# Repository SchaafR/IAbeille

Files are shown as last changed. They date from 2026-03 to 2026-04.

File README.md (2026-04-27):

# IABEILLES — Système de surveillance de ruches intelligent





**IABEILLES** est une solution IoT (Internet des Objets) développée à Polytech Sorbonne pour protéger les colonies d'abeilles contre la prédation des frelons asiatiques. Le système utilise l'intelligence artificielle pour la détection visuelle et sonore, tout en transmettant des données environnementales via le réseau LoRaWAN.

---

## Table des Matières
* [Présentation](#-présentation)
* [Spécifications Matérielles](#-spécifications-matérielles)
* [Installation Logicielle](#-installation-logicielle)
* [Configuration Réseau (LoRaWAN/TTN)](#-configuration-réseau)
* [Mise en Service](#-mise-en-service)
* [Équipe](#-équipe)

---

## Présentation

### Mission
Transformer des mesures physiques en **informations exploitables** pour les apiculteurs et chercheurs. Le système surveille en temps réel :
* **Détection visuelle** (IA) : Identification des abeilles et frelons.
* **Détection sonore** : Analyse de l'activité acoustique.
* **Environnement** : Température, humidité et luminosité.

### Architecture de communication
`Capteurs (I2C/Analog)` ➔ `ESP32S3 / Nano BLE` ➔ `Module LoRa E5` ➔ `Passerelle LoRaWAN` ➔ `TTN` ➔ `Bleep (Dashboard)`

---

## Spécifications Matérielles

| Composant | Rôle Principal |
| :--- | :--- |
| **XIAO ESP32S3 Sense** | Cœur de l'IA (Vision) & Caméra |
| **Arduino Nano BLE Sense** | Analyse sonore & Gestion des capteurs |
| **Module LoRa E5** | Communication longue portée |
| **DHT22 & BH1750** | Monitoring Température/Humidité/Lumière |
| **Panneau Solaire & LiPo** | Autonomie énergétique (3.7V 1000mAh) |
| **PCB Custom** | Interconnexion et robustesse |

---

## Installation Logicielle

### 1. Prérequis
* [Arduino IDE](https://www.arduino.cc/en/software)
* Support de carte **ESP32 by Espressif Systems** (via le gestionnaire de cartes).
* Support de carte **Arduino Mbed OS Nano Boards**.

### 2. Récupération du projet
```bash
git clone https://github.com/SchaafR/IAbeille.git
```

### 3. Installation des Librairies Custom (IA)
Les modèles d'inférence sont fournis sous forme d'archives `.zip` dans le dossier `/data`.
1. Localisez votre dossier Arduino (ex: `Documents/Arduino/libraries`).
2. Décompressez-y les fichiers suivants :
   - `BeeGuardAI_Hornet_Bee_Bees_G1V2_inferencing.zip`
   - `Hornets_lib_3.zip`
3. Redémarrez l'IDE Arduino.

### 4. Dépendances Standard
Installez via le **Library Manager** d'Arduino :
* `DHT sensor library`
* `BH1750`

---

## Configuration Réseau

### The Things Network (TTN)
Le module LoRa E5 utilise l'activation **OTAA**.
1. **Créer une application** sur [TTN Console](https://console.cloud.thethings.network/).
2. **Enregistrer l'appareil** avec les identifiants présents dans le code source :
   - `DevEUI`
   - `AppEUI` / `JoinEUI`
   - `AppKey`
3. **Payload Formatter** : Utilisez le script JavaScript situé dans `/src/payload_formatter` pour décoder les trames hexadécimales en données lisibles.

---

## Mise en Service

### Flashage des cartes
1. Ouvrez `COM_N_AI.ino` dans Arduino IDE.
2. Connectez le **XIAO ESP32S3**.
3. Sélectionnez le port correspondant et le type de carte **XIAO_ESP32S3**.
4. Cliquez sur **Upload** (→).
5. Répétez l'opération pour l'Arduino Nano avec le fichier `hornet_lib_3.ino`.

### Déploiement physique
> [!IMPORTANT]
> Vérifiez l'étanchéité du boîtier et le serrage des presse-étoupes avant l'installation en extérieur.

1. Actionnez le bouton **On/Off**.
2. Un **bip sonore (0.5s)** confirme l'initialisation du système.
3. Vérifiez la LED de charge (Panneau Solaire/Batterie).
4. Surveillez l'onglet **Live Data** sur TTN pour confirmer la réception des premières trames.

---

## Équipe (Rédacteurs)

* **Léo Dupuy**
* **Amine Filahi**
* **Benoit Lavieville**
* **Marguerite Massinga**
* **Rémy Schaaf**

---

## Remerciements
Projet réalisé dans le cadre de la 4ème année à **Polytech Sorbonne**. Merci à l'équipe pédagogique et aux encadrants pour leur soutien technique et méthodologique.

## Contacte
En cas de problème ou de questions, vous pouvez nous contacter à l'adresse : schaarem@gmail.com

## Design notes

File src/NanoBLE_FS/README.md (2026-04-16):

# Installation des dépendences

- Vérifie que HornetAudio.h est présente dans le dossier.
- Importer hornet_lib_3.zip dans l'IDE arduino (Sketch/Include Library/Include ZIP lib..)

# Variables globales de test 

- Mettre DEBUG @1
- Mettre Modefonctionnement @2

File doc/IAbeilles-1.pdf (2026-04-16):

# IAbeilles

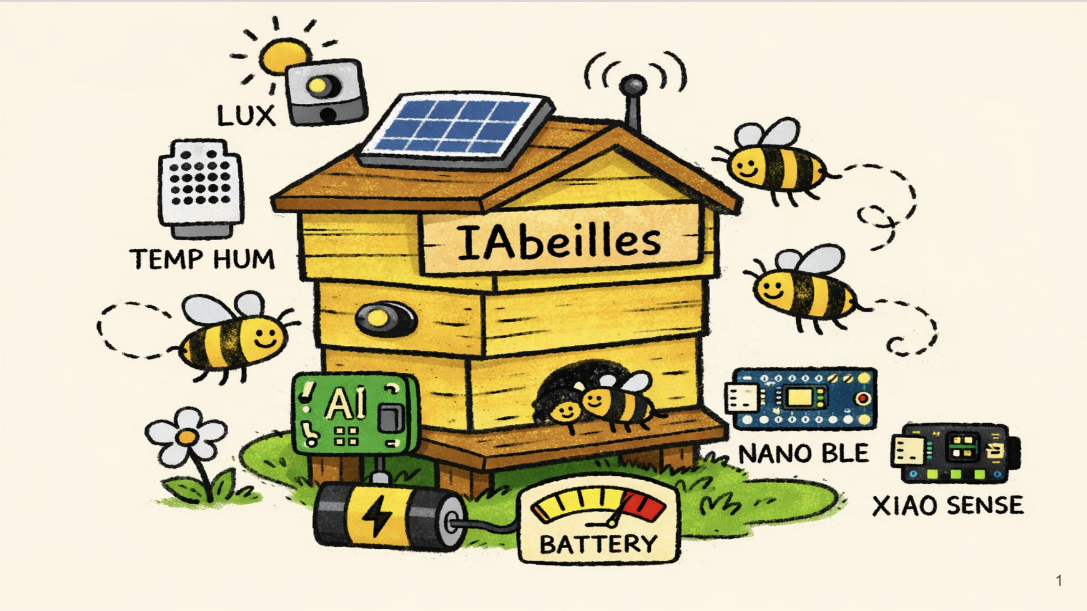
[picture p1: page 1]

- Léo Dupuy
- Amine Filahi
- Benoit Lavieville
- Marguerite Massinga
- Rémy Schaaf

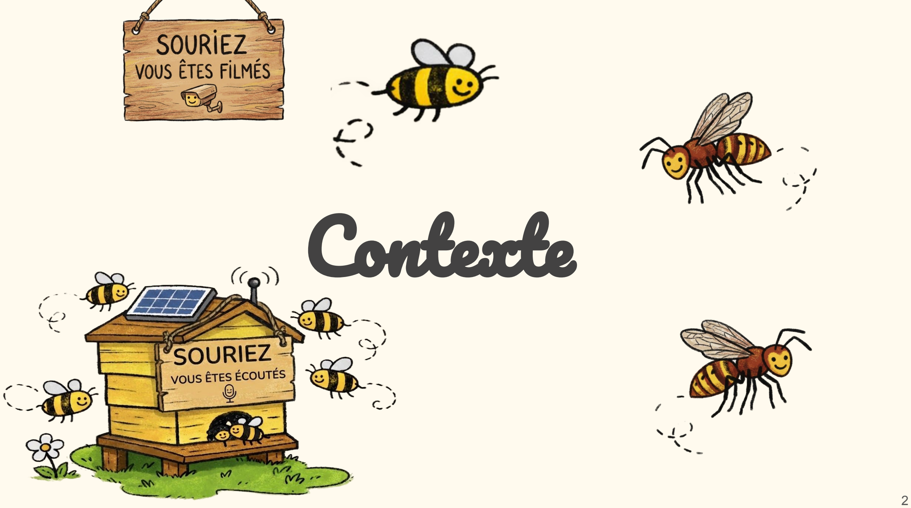
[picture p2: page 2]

# Contexte

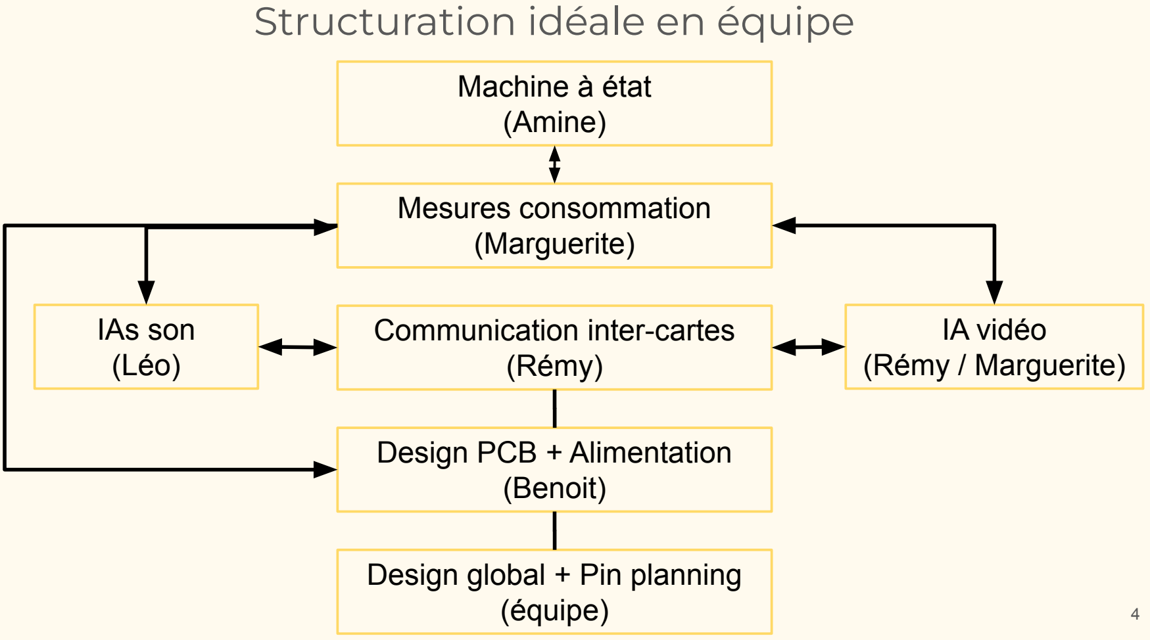
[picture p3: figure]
Structuration idéale en équipe; IAs son (Léo); IA vidéo (Rémy / Marguerite); Design PCB + Alimentation (Benoit); Mesures consommation (Marguerite); Machine à état (Amine); Design global + Pin planning (équipe); Communication inter-cartes (Rémy)
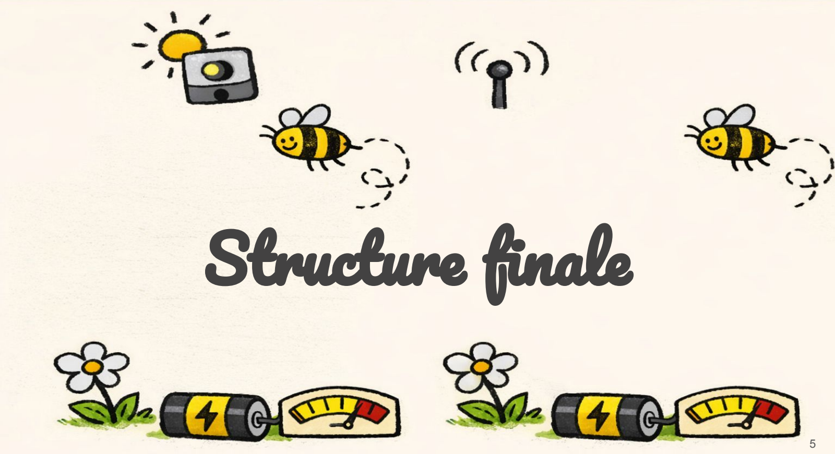
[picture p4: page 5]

# Structure finale

# Schéma fonctionnel de la solution

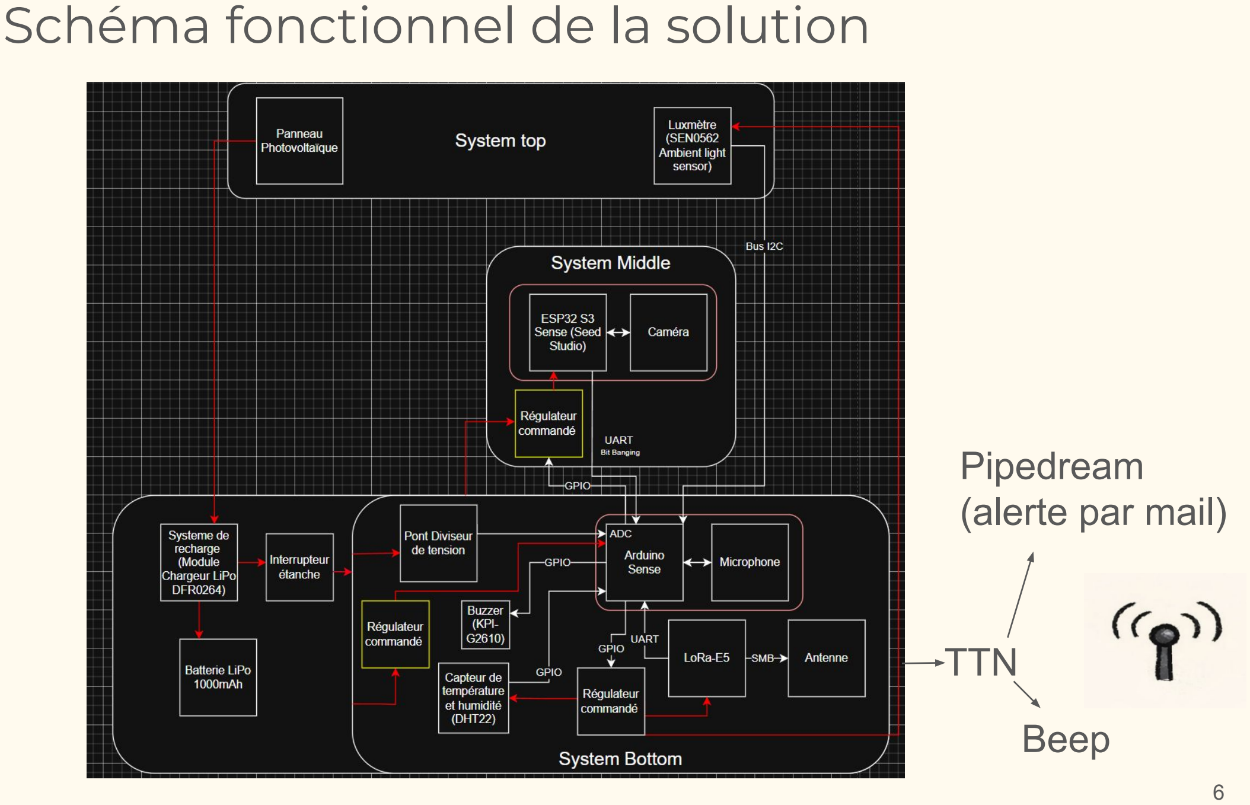
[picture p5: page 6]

TTN

Pipedream
(alerte par mail)

Beep

# PCB & Schéma électronique XIAO

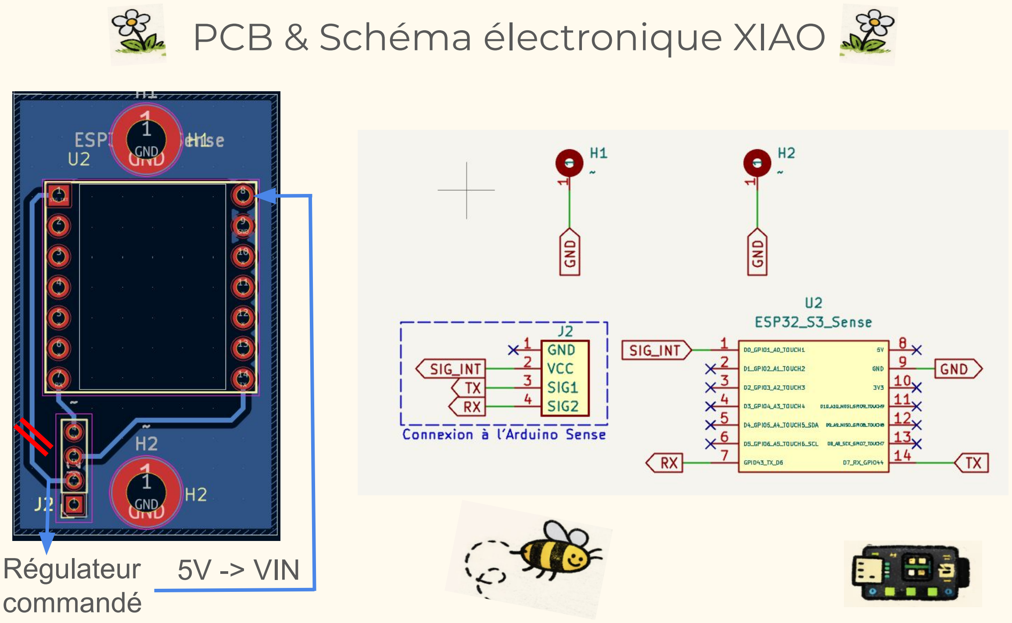
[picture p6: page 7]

Régulateur
commandé

5V -> VIN

### Flowchart complet du système

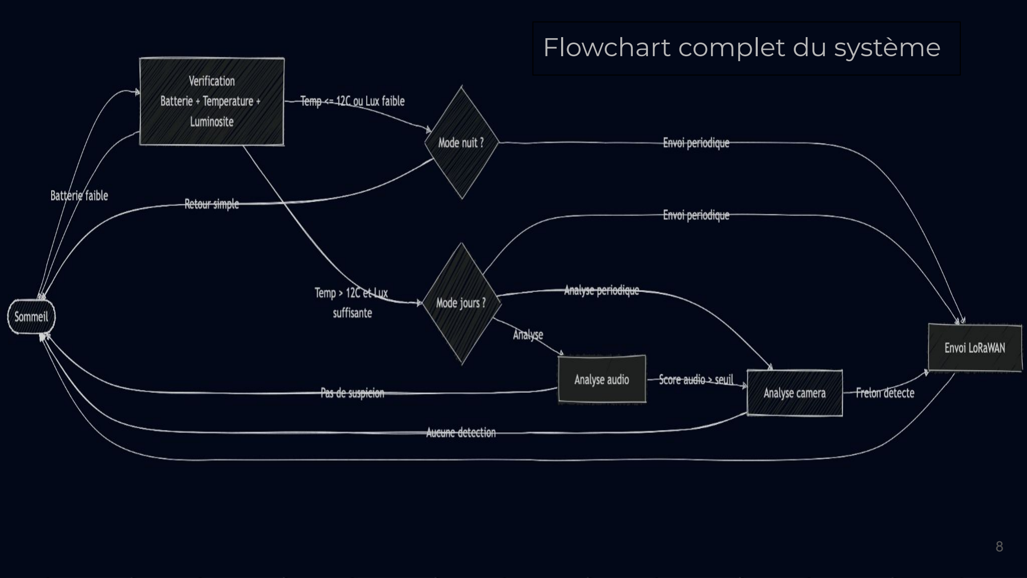
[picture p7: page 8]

# Mesures et consommation

# Comparaison Mesure VS Météo

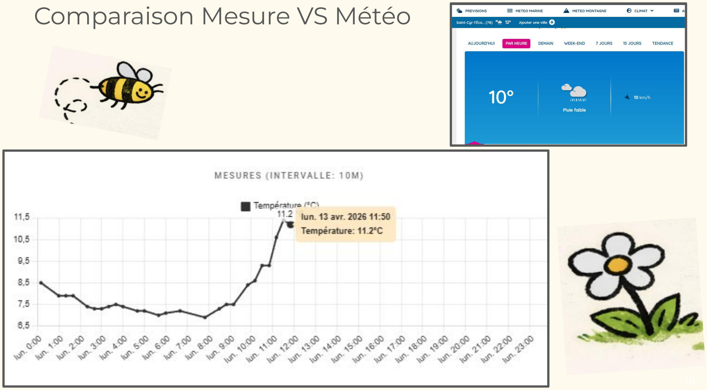
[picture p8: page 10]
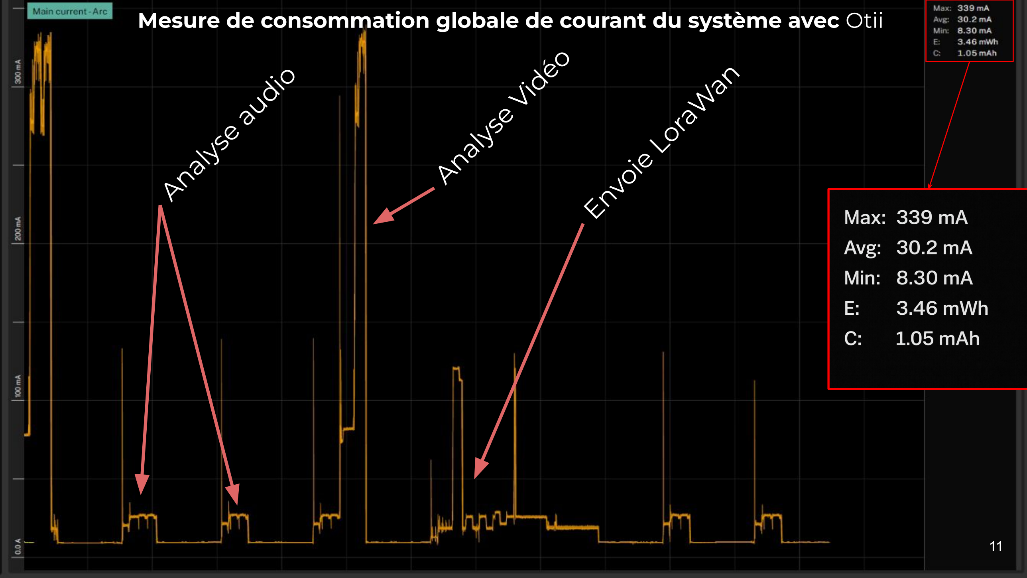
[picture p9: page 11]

Mesure de consommation globale de courant du système avec Otii

## Analyse audio

## Analyse Vidéo Envoie LoraWan

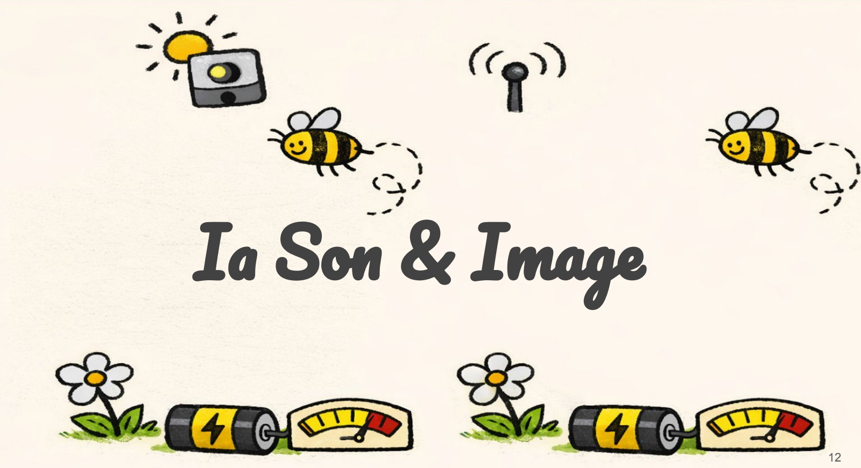
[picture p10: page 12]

# Ia Son & Image

## IA Son

# Détection sonore des frelons et de la reine

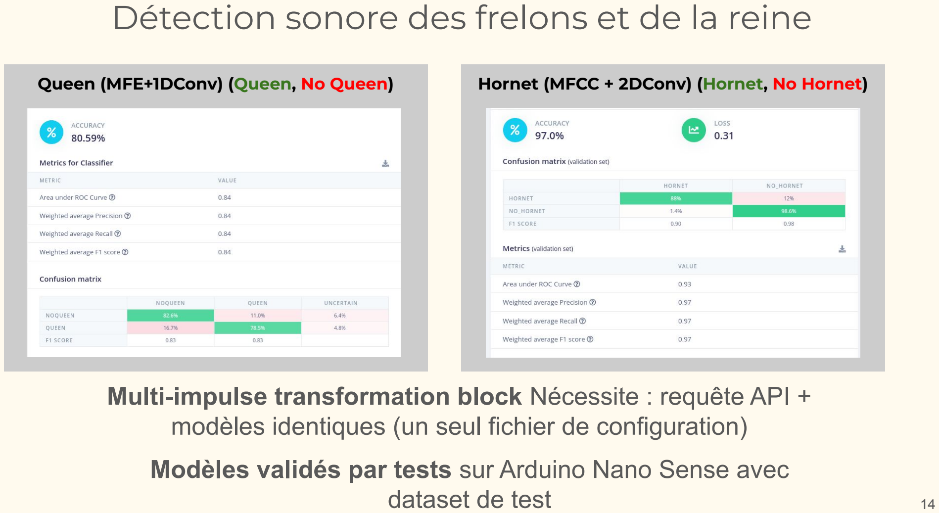
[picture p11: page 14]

Queen (MFE+1DConv) (Queen, No Queen) | Hornet (MFCC + 2DConv) (Hornet, No Hornet)

Multi-impulse transformation block Nécessite : requête API + modèles identiques (un seul fichier de configuration)

Modèles validés par tests sur Arduino Nano Sense avec dataset de test

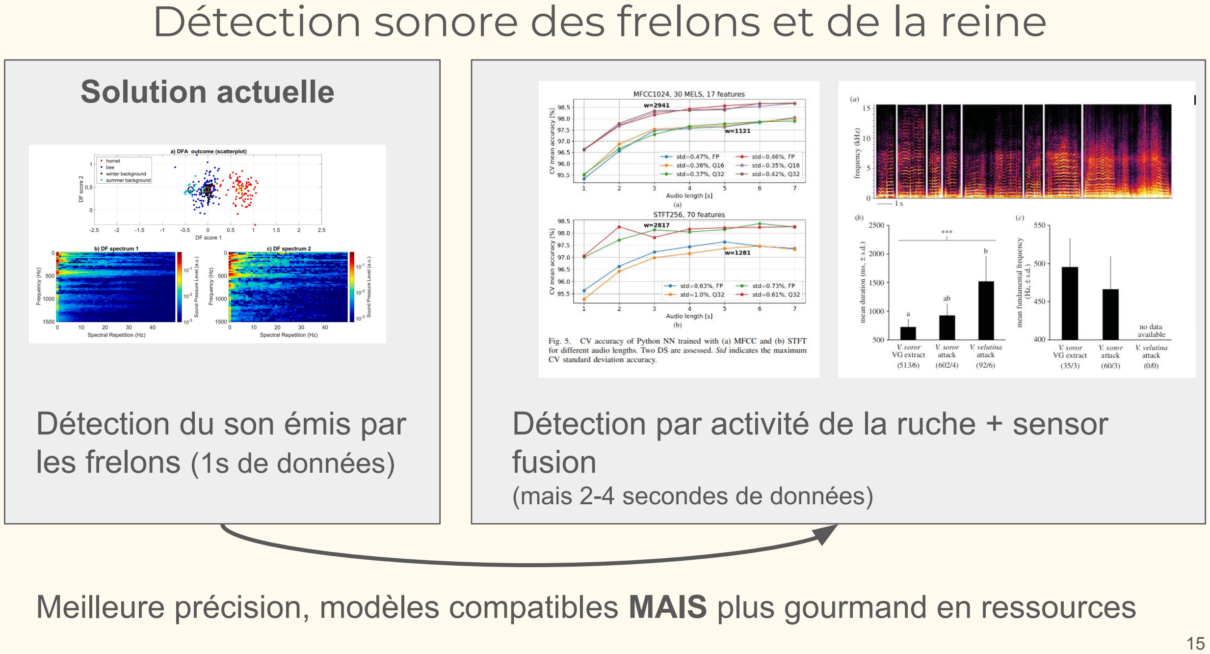
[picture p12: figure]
fusion; (mais 2-4 secondes de données); Détection du son émis par les frelons (1s de données); Solution actuelle

# Détection sonore des frelons et de la reine

Détection par activité de la ruche + sensor

Meilleure précision, modèles compatibles MAIS plus gourmand en ressources

### Espace mémoire occupé par le modèle de reconnaissance son

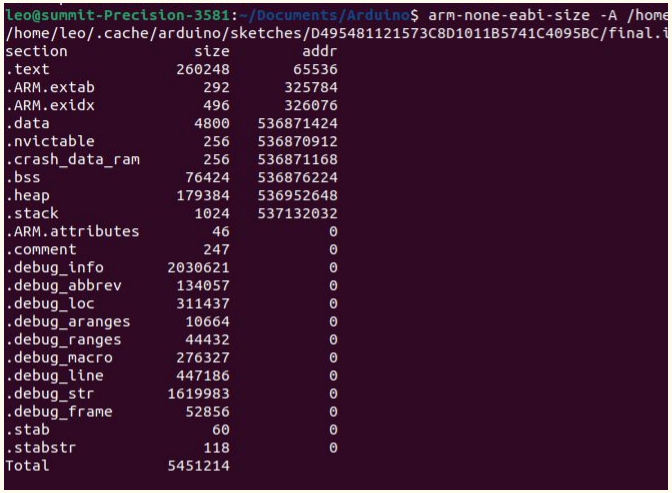
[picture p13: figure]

## IA Image

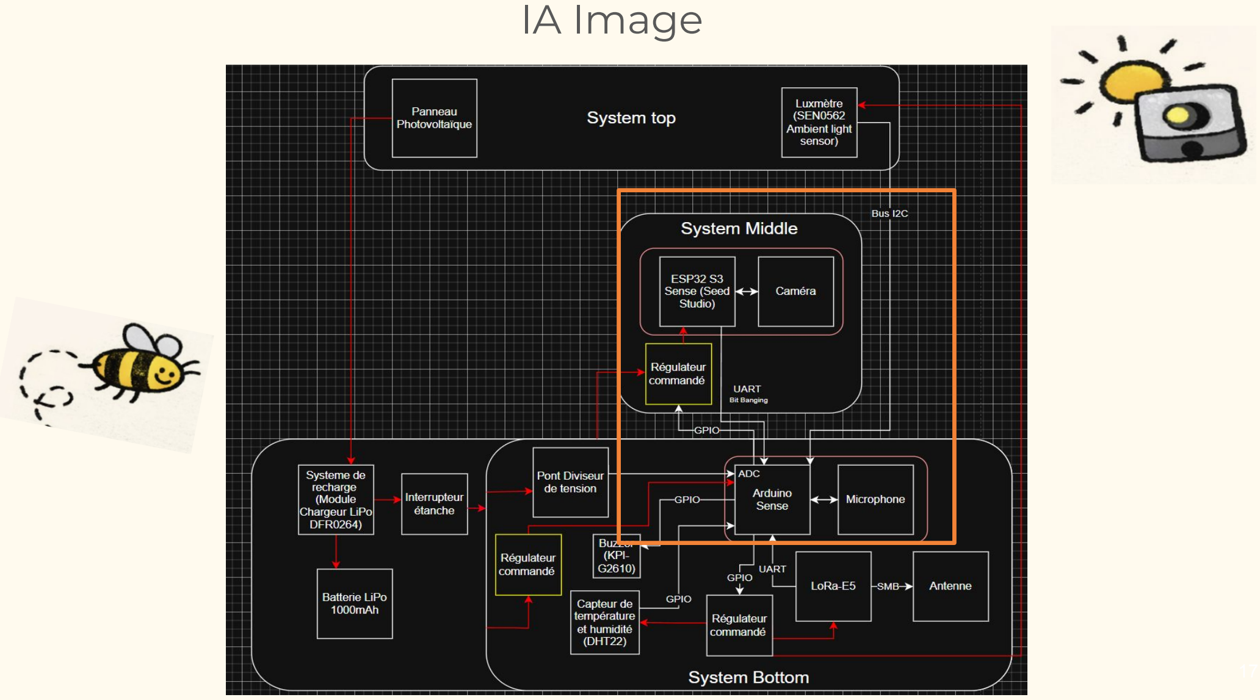
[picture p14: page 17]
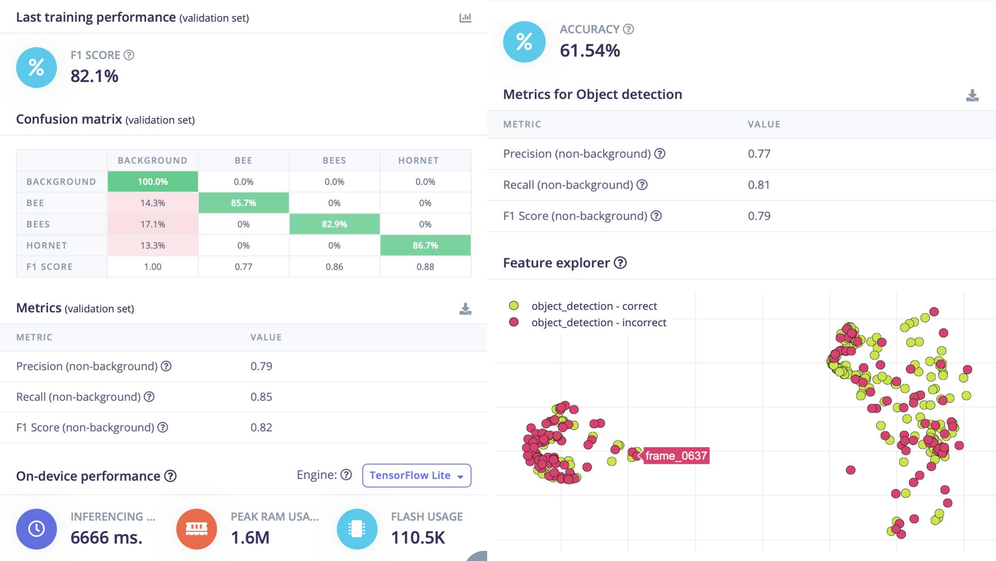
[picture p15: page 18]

# Résultats de l’IA avec Model 240x240

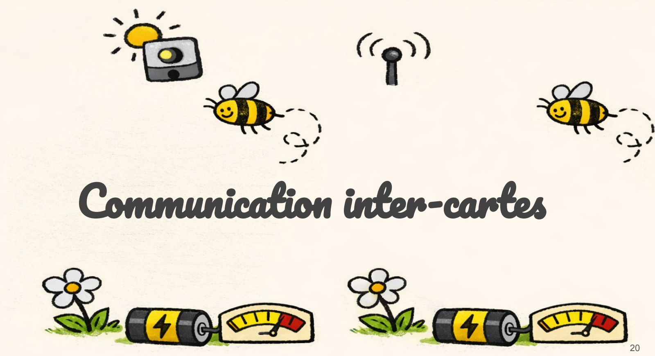
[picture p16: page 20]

# Communication inter-cartes

# Flowchart communication entre les deux cartes

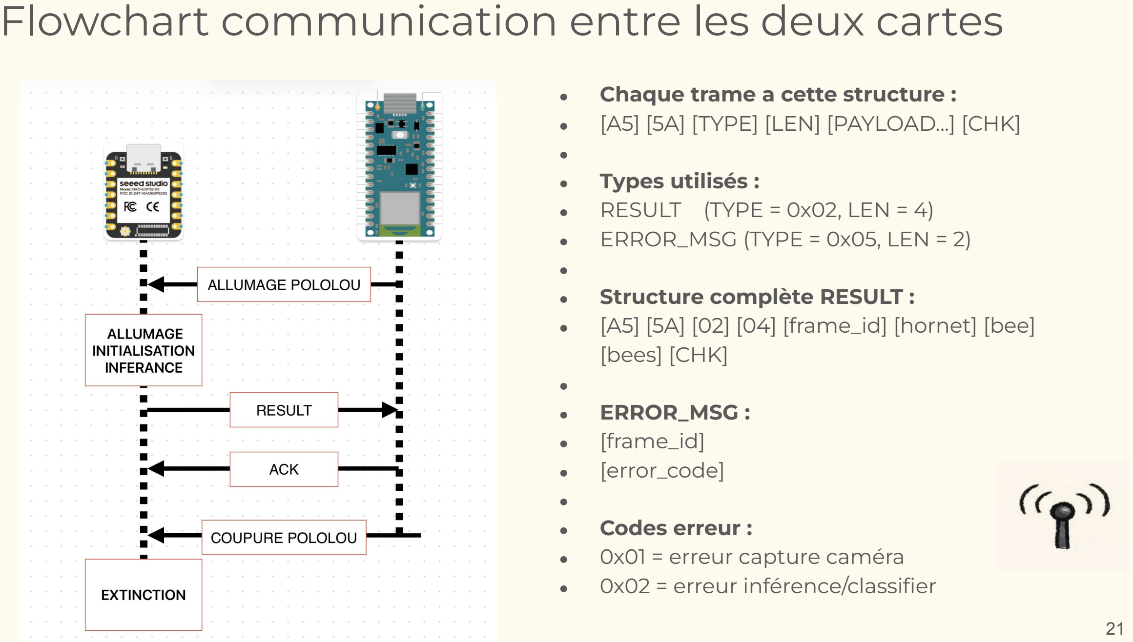
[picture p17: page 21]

- Chaque trame a cette structure :
- [A5] [5A] [TYPE] [LEN] [PAYLOAD...] [CHK]

●
- Types utilisés :
- RESULT (TYPE = 0x02, LEN = 4)
- ERROR_MSG (TYPE = 0x05, LEN = 2)

●
- Structure complète RESULT :
- [A5] [5A] [02] [04] [frame_id] [hornet] [bee] [bees] [CHK]

●
- ERROR_MSG :
- [frame_id]
- [error_code]

●
- Codes erreur :
- 0x01 = erreur capture caméra
- 0x02 = erreur inférence/classifier

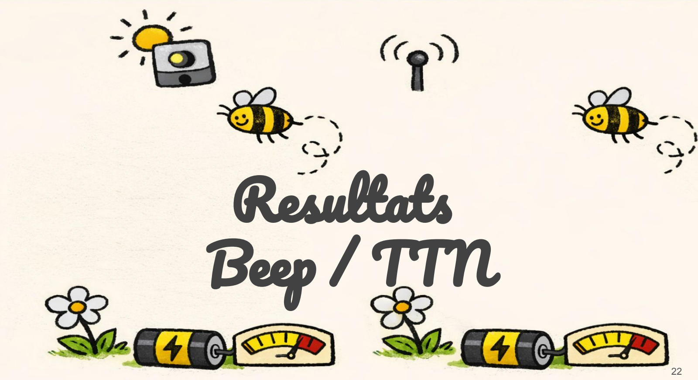
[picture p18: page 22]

# Resultats Beep / TTN

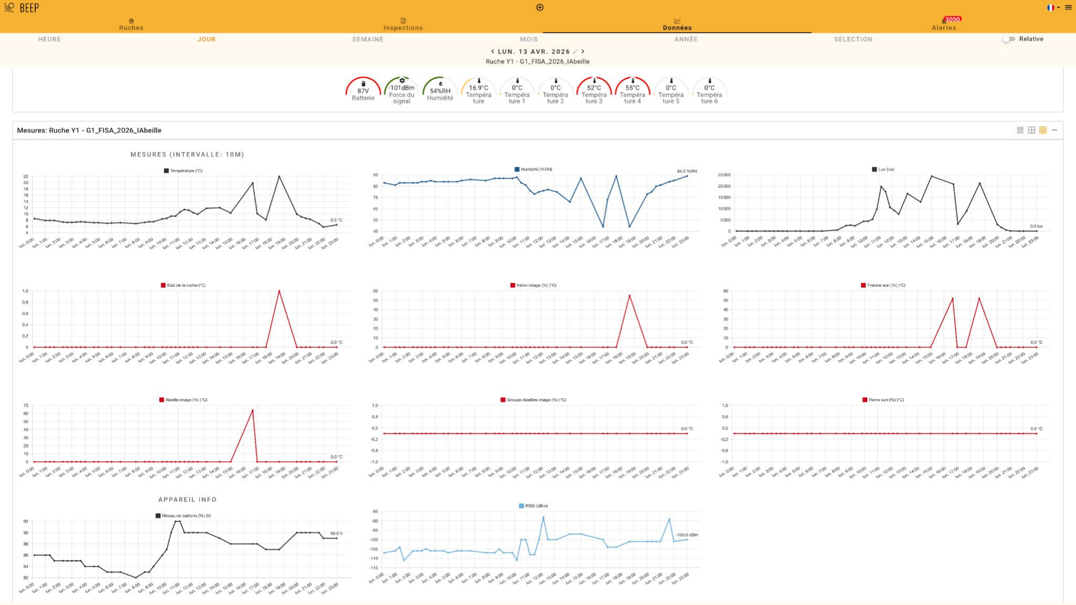
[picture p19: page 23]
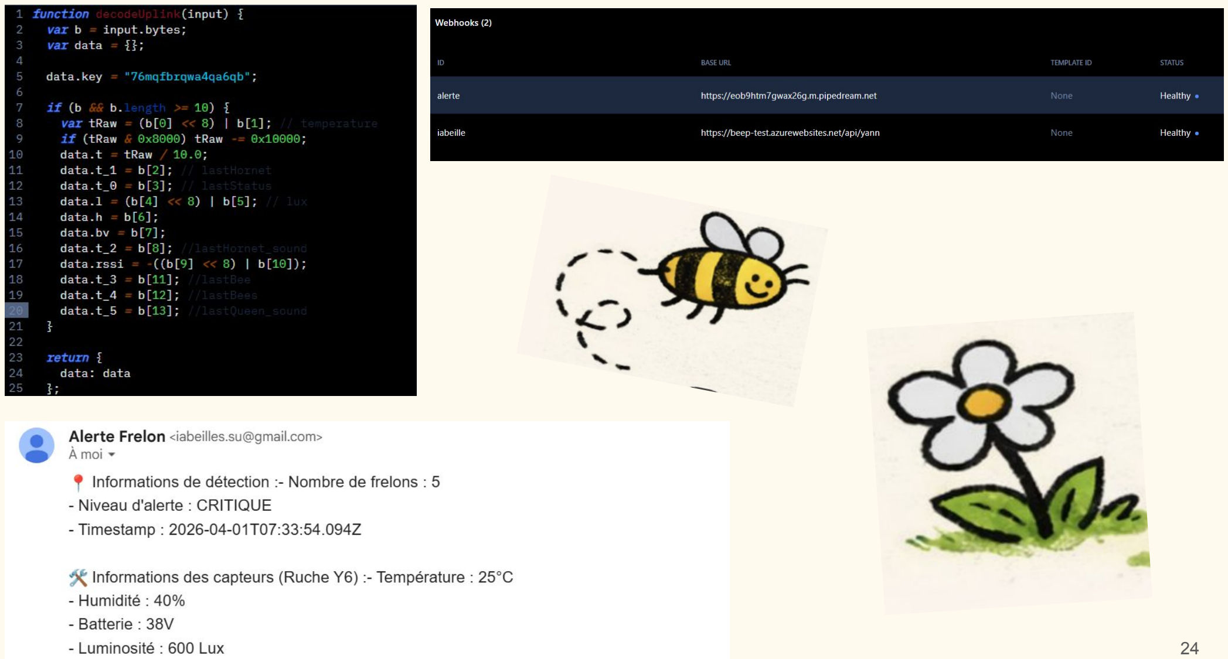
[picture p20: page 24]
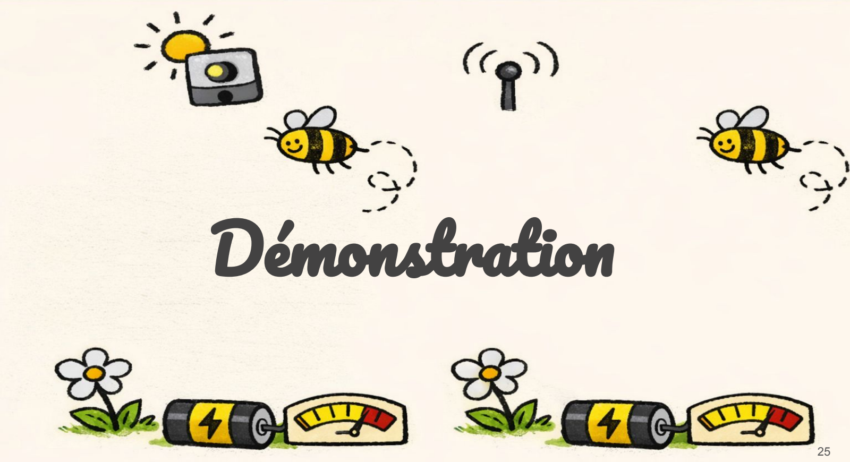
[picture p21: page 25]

# Démonstration

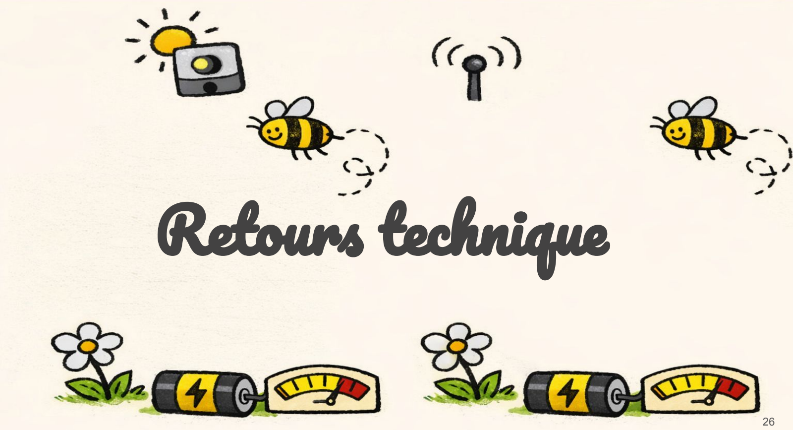
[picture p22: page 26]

# Retours technique

27

Audio
- Concaténation de modèles difficile (librairies C++)
- Arduino Nano Sense demandé par le client non adatpé au projet (RAM limitée (enregistrement de 2s plus intéressant)
- Positionnement du microphone (VS Dataset)
Energie
- Gestion de l’énergie suffisante : estimation non précise mais validation empirique.
Machine à état
- MAE non intelligente : détection difficile.
IA
- Manque de dataset : Détection frelon par activité sonore de la ruche aurait été pertinente (nécessite 2-6 secondes)

# Points limitants

# Retour de gestion :

# Methode Scrum / Post Scrum

## Constats

### - Les points courts et réguliers sont efficaces - Les sprints aident à rythmer l’avancement - La répartition initiale des tâches fonctionne bien

Axes d’apprentissage:

### - Mieux cadrer dès le début du projet - Prévoir un pilotage clair et identifié - Renforcer les revues intermédiaires

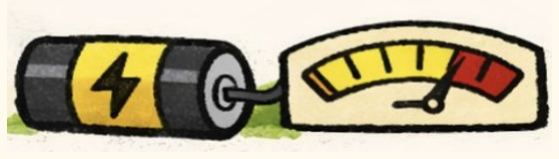
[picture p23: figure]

### - Mettre en place un suivi simple, en amont de projet - Prévoir un échange client spécifique sur les données

# Vers une organisation plus adaptée

# Questions ?

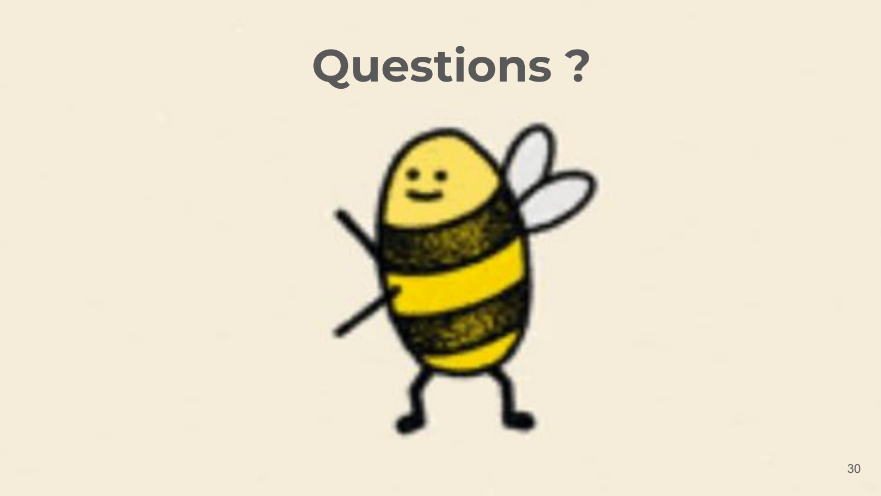
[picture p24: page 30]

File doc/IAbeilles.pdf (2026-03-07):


# IAbeilles

- Léo Dupuy
- Amine Filahi
- Benoit Lavieville
- Marguerite Massinga
- Rémy Schaaf

## - Répartition des rôle

## - Outils de gestion de projet utilisé

## - Budget prévisionnel

## - Liste du matériel utilisé

## - Schéma fonctionnel de la solution

## - Schéma électronique

## - Traitement du signal audio & IA embarquée

# TABLE DES MATIÈRES

Pôles
- Electronique - Amine Benoit
- Energie - Benoit Léo
- Algorithmie / C embarqué - Amine Marguerite
- IA embarqué - Léo Amine
- LoraWAN / Cloud - Rémy Léo
- Assemblage / Mécanique / 3D - Rémy
- Gestion de projet - Rémy Marguerite

Rôles
- Scrum Master - Léo
- Product owner - Amine
- Intendance / animation - Marguerite

# Répartition des rôles

# Outils de gestion de projet Utilisé

01 | Gestion du projet : Trello
02 | Suivi de versions soft : GitHub


03 | Suivre l'avancement : PowerPoint
04 | Communication : WhatsApp

# Budget prévisionnel

Salariés | Montant € (heurs) | Quantité (séance + perso) | Total €
Léo | 25 | 104 | 2600
Amine | 25 | 104 | 2600
Benoit | 25 | 104 | 2600
Marguerite | 25 | 104 | 2600
Rémy | 25 | 104 | 2600
TOTAL | | | 13000

FORMULE : 60 h en salle + 4 h perso * 11 Semaines

# Liste du matériel

Matériel électronique | Coût unitaire | Quantité | Total
ESP32-S3 Sense | 13,90 € | 1 | 13,90 €
Arduino Sense | 44,60 € | 1 | 44,60 €
Capteur de température (DHT22) | 8,55 € | 1 | 8,55 €
Résistance (¼ W 5%) | 0,20 € | 3 | 0,60 €
Buzzer (KPI-G2610) | 2,81 € | 1 | 2,81 €
Module LoRa (Lora-E5) | 19,95 € | 1 | 19,95 €
SEN0562 (Ambient Light Sensor) | 7,65 € | 1 | 7,65 €
Panneau Photovoltaïque | 12,90 € | 1 | 12,90 €
Antenne | 8,30 € | 1 | 8,30 €
Bouton d'alimentation | 2,80 € | 1 | 2,80 €
Système de recharge de batterie (Module Chargeur LiPo DFR0264) | 5,20 € | 1 | 5,20 €
Batterie (LiPo 1000 mAh) | 9,90 € | 1 | 9,90 €
Régulateur Pololu (S7V8F3) | 11,00 € | 1 | 11,00 €
TOTAL | | | 148,16€

# Liste du matériel

Matériel autre | Coût unitaire | Quantité | Total
Tendeur | 2,00 € | 2 | 4,00 €
Impression 3D / Découpe laser | - | - | -
PCB | ~50 | 2 | ~100
Câbles | 0,20 € | - | 10,00 €
Boitier étanche | 5,90 € | 1 | 5,90 €
Joint d'étanchéité | 6,00 € | (assortiment) | 6,00 €
Presse-étoupe | 1,00 € | 3 | 3,00 €
Breadboard | 5,90 € | 1 | 5,90 €
TOTAL | | | 134,80€

# Schéma fonctionnel de la solution


# Schéma électronique

## Carte ESP32 S3 Sense :


## Schéma électronique carte Arduino Sense :



## PCB carte Arduino Sense :

# Premiers résultats détection Frelon

Problème initial : crash systématique après démarrage, avec message :
- CORRUPT HEAP: Bad head ...
- assert failed: multi_heap_free …

Solution :
- Utiliser Tensor Flow lite à la compilation pour des questions de compatibilité
- Travailler avec un model plus petit 240x240 -> 96x96

Déroulé :
Première étape : Validation du modèle sans caméra
- Le modèle était compatible avec l’ESP32S3
- La mémoire PSRAM était suffisante
- Le pipeline Edge Impulse fonctionnait

Adaptation du pipeline image
OV2640 (RGB565 320x240)
↓
Conversion RGB888
↓
Resize 96x96
↓


Normalisation (-128) -> run_classifier() -> FOMO bounding boxes

# Traitement du signal audio & IA embarquée


- Prétraitement avec PyTorch
- Ajout de bruits saisonniers
- Entraînement sur PC ou kaggle
- Conversion vers format embarqué (.tflite)

# Conclusion

## Constat sur le fonctionnement de l’équipe :

## - Répartition équilibrée des tâches

## - Bonne implication de toute l’équipe

## - Bonnes idées et bons apports techniques

## Axe d’amélioration et actions à mettre en place:

## - Communiquer plus régulièrement sur les avancées individuelles

## - Avoir une prise de décision plus rapide

## - Systématiser l’usage des outils de gestion de projet (trello…)

# Questions ?


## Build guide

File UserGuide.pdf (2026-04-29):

## IABEILLES

Sorbonne Université, 4 place Jussieu, 75005 Paris, France 2025/2026

# GUIDE UTILISATEUR

## Rédacteurs:

- Léo Dupuy,
- Amine Filahi,
- Benoit Lavieville,
- Marguerite Massinga,
- Rémy Schaaf

# 1. Objectif du document

Au travers de ce document on se propose de fournir un guide qui permet de mettre en œuvre la solution que l’équipe IABEILLES à développé au cours du second semestre d’année 4 de la Formation EI (Électronique et Informatique) de Polytech Sorbonne.

# 2. Présentation du projet

Pour répondre à la menace croissante des frelons asiatiques, nous avons développé le projet IABEILLES. C’est un système connecté conçu pour surveiller une ruche automatiquement.
Il collecte en temps réel des informations utiles grâce à différents capteurs, puis analyse ces données pour aider à mieux comprendre l’état de la colonie.

L’objectif n’est pas seulement de mesurer, mais de transformer ces mesures en informations faciles à exploiter. Les données peuvent ensuite être consultées via l’API Beep, afin de suivre l’activité de la ruche, repérer plus rapidement certaines anomalies et faciliter la prise de décision.

Concrètement, ce système permet à l’apiculteur ou au chercheur d’installer une solution de suivi sur une ruche et d’obtenir une vision plus claire de son fonctionnement, sans intervention permanente. IABEILLES associe ainsi internet des objet (IoT) et apiculture pour proposer un outil de surveillance moderne, simple à déployer et utile au quotidien.

# 2.1. Mission et Objectif

La mission d’IABEILLES est de proposer une solution fiable et intelligente pour surveiller en temps réel l’activité des frelons autour des ruches. Face à la pression prédatrice qui menace les colonies, ce système devient un outil précieux pour les apiculteurs et les chercheurs.

En combinant l’intelligence artificielle et des capteurs adaptés aux conditions extérieures, il permet de suivre l’activité devant la ruche de manière plus précise, tout en tenant compte des contraintes environnementales.

L’objectif n’est pas seulement de détecter la présence de frelons, mais aussi d’apporter une vision plus claire de la pression exercée sur les ruches afin de mieux protéger les abeilles.

# 3. Détail du matériel

Matériel | Quantité | Coût unitaire | Coût total | Fonction
XIAO ESP32S3 Sense | 1 | 16,90€ | 16,90€ | Intègre le module IA pour la détection visuelle des abeilles et des frelons.
Module LoRa (E5) | 1 | 18,90€ | 18,90€ | Envoie les informations vers TTN.
DHT22 | 1 | 17,10€ | 17,10€ | Recueillir la température et l’humidité environnante des ruches.
Capteur de lumière BH1750 ADA4681 | 1 | 5,90€ | 5,90€ | Détecter la présence de la lumière et son intensité.
Batterie LiPo 3,7 Vcc 1000 mAh MB-P3090003 | 1 | 23,90€ | 23,90€ | Alimentation principale du système.
Arduino Nano ble Sense | 1 | 42,65€ | 42,65€ | Intègre le modèle de détection des sons autours de la ruche, récupère les informations des capteurs
Buzzer | 1 | 2,81€ | 2,81€ | Alerte sonore pour indiquer la mise en activité du système.
Module chargeur LiPo DFR0264 | 1 | 5,20 € | 5,20€ | Chargeur solaire alimentant la batterie.
Antenne Lora | 1 | 8,30€ | 8,30€ | Envoie et reçoit les données du module Lora.
Panneau Photovoltaïque | 1 | 12,90€ | 12,90€ | Recharge la batterie
Régulateur Pololu 3.3V | 1 | 11,00€ | 11,00€ | Abaisse la tension en sortie de la batterie pour alimenter la carte Arduino en 3.3V.
Régulateur Pololu 5V | 1 | 11,00€ | 11,00€ | Permet d’avoir en sortie du 5V.
Résistance (¼ W 5%) | 3 | 0,20€ | 0,60€ | permet de faire le diviseur de tension pour contrôler le niveau de batterie
Bouton d'alimentation | 1 | 2,80€ | 2,80€ | Permet d’allumer et éteindre le système.
Tendeur | 2 | 2,00€ | 4,00€ | fixer le boitier de caméra à la ruche
Impression 3D / Découpe laser | | | 0,00€ | Imprimer le PCB et autres composants.
PCB | 2 | 50,00€ | 100,00€ | Assure les connexions électriques entre les

| | | | composants du circuit.
Câbles | | 0,20€ | 0,00€ | Liaison des différents éléments entre eux.
Boitier étanche | 1 | 5,90€ | 5,90€ | Isole le circuit des agressions extérieures(pluie, neige,..).
Joint d'étanchéité | | 6,00€ | 0,00€ | assure l'étanchéité du système
Presse-étoupe | 3 | 1,00€ | 3,00€ | permet de faire les transition de paroies
Breadboard | 1 | 5,90€ | 5,90€ | Permet de faire les tests du système avant la mise en relation sur PCB.

Gardez à l’esprit que les composants sélectionnés et les prix indiqués ne représentent pas nécessairement la solution idéale, mais plutôt la solution retenue en fonction de la disponibilité et du coût des composants au moment du projet. Vous êtes libre de choisir les composants qui vous conviennent le mieux et d’adapter le système en conséquence.

Les prix indiqués correspondent à l’année 2026 et sont susceptibles d’évoluer avec le temps.

# 4. montage materiel

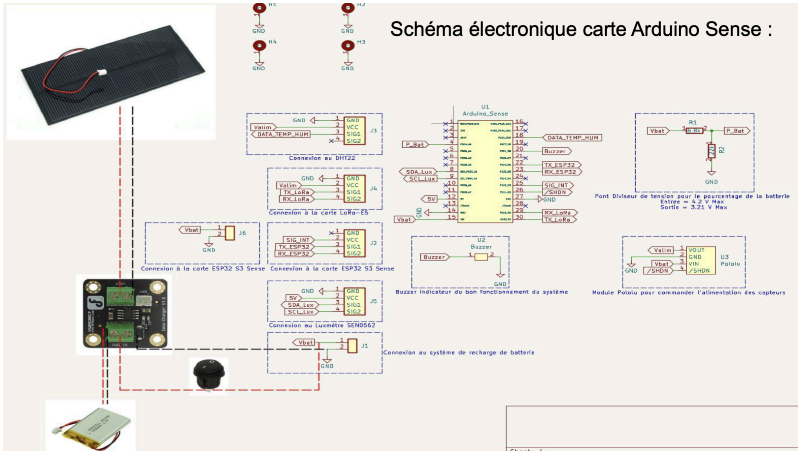
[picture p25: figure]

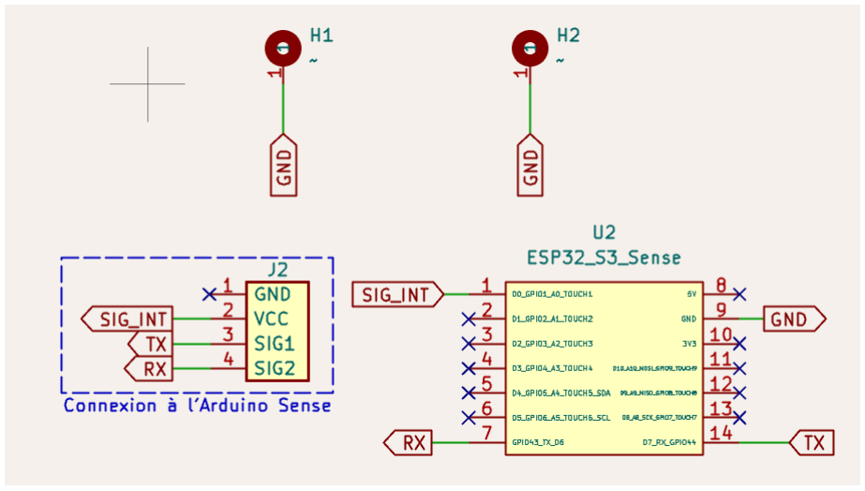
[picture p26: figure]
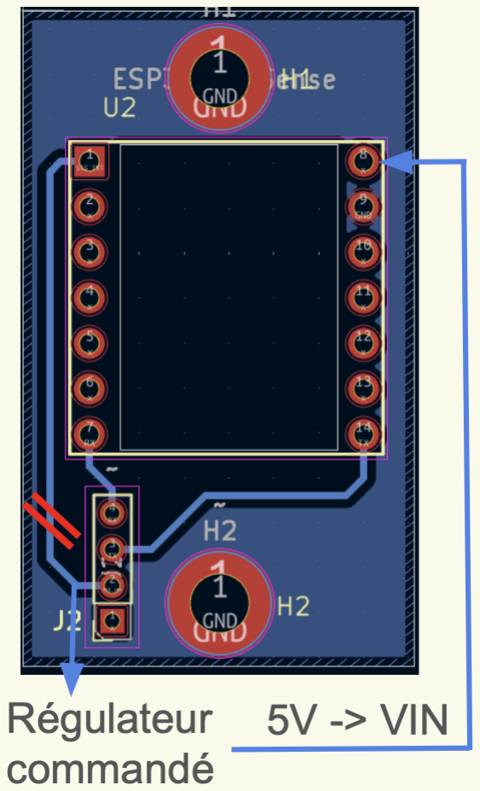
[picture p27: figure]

Ci-dessous les schémas de câblage des deux cartes. Attention à respecter le schéma suivant pour que le code soit fonctionnel. Si vous souhaitez utiliser une architecture différente, il conviendra d’adapter le code ainsi que votre PCB.

# 5. logiciel requis

### 5.1. Arduino IDE

Le logiciel Arduino IDE est un logiciel qui vas vous permettre d'écrire, visualiser du code et flasher du code sur les cartes.

### 5.2. The Thing Network (TTN)

the thing network est une platform qui permet de récupérer les donné transmise par le système

### 5.3. Bleep

Bleep est une plateforme qui permet de visualiser les données récupérées par TTN

# 6. Installation logiciel

### 1. Télécharger le code source

Pour installer l’outil, vous devez d’abord récupérer le code source depuis GitHub.

Rendez-vous sur le dépôt GitHub du projet à l’adresse suivante : https://github.com/SchaafR/IAbeille

Une fois sur la page du dépôt, cliquez sur le bouton vert <> Code.

Deux méthodes de téléchargement sont possibles :

Option 1 : Cloner le dépôt avec Git

Si Git est installé sur votre ordinateur, vous pouvez copier l’URL du dépôt, puis exécuter la commande suivante dans un terminal :

git clone https://github.com/SchaafR/IAbeille.git

Cette commande téléchargera automatiquement le projet sur votre ordinateur.

Option 2 : Télécharger le projet au format ZIP

Si vous ne souhaitez pas utiliser Git, vous pouvez télécharger directement le projet.

Pour cela :

1. Cliquez sur le bouton <> Code.
2. Cliquez ensuite sur Download ZIP.
3. Une fois le téléchargement terminé, ouvrez le fichier ZIP.
4. Extrayez son contenu dans le dossier de votre choix.

Le code source du projet est maintenant disponible sur votre ordinateur.

## Installation d’Arduino IDE

### 1. Télécharger Arduino IDE

Pour utiliser l’outil, vous devez installer Arduino IDE sur votre ordinateur. Arduino IDE est le logiciel qui permet d’écrire, de vérifier et d’envoyer du code vers une carte Arduino ou compatible.

Rendez-vous sur le site officiel d’Arduino à l’adresse suivante : https://www.arduino.cc/en/software

Une fois sur la page, choisissez la version adaptée à votre système d’exploitation :

- Windows
- macOS
- Linux

Cliquez ensuite sur le bouton de téléchargement correspondant.

### 2. Installer Arduino IDE

Sur Windows

Une fois le fichier téléchargé :

1. Ouvrez le fichier d’installation.
2. Acceptez les conditions d’utilisation.
3. Laissez les options d’installation par défaut.
4. Cliquez sur Install.
5. Une fois l’installation terminée, cliquez sur Finish.

Arduino IDE est maintenant installé sur votre ordinateur.

Sur macOS

Une fois le fichier téléchargé :

1. Ouvrez le fichier .dmg.
2. Glissez l’application Arduino IDE dans le dossier Applications.
3. Ouvrez ensuite Arduino IDE depuis le dossier Applications.

Lors du premier lancement, macOS peut demander une confirmation de sécurité. Dans ce cas, autorisez l’ouverture de l’application.

Sur Linux

Une fois le fichier téléchargé :

1. Extrayez l’archive téléchargée.

2. Ouvrez le dossier extrait.
3. Suivez les instructions d’installation fournies sur le site officiel d’Arduino.

### 3. Vérifier l’installation

Après l’installation, ouvrez Arduino IDE.

Si le logiciel se lance correctement, l’installation est terminée. Vous pourrez ensuite connecter votre carte Arduino à l’ordinateur et configurer le type de carte ainsi que le port utilisé.

## Installation d’une librairie Arduino depuis un dossier local

Le modèle d'intelligence artificielle est contenue sous forme de librairie arduino. Il faut donc l’inclure dans vos librairie pour que le projet fonctionne

### 1. Récupérer la librairie

Cette librairie est déjà fournie avec le projet. Elle se trouve dans le dossier suivant :

IAbeille/data/BeeGuardAI_Hornet_Bee_Bees_G1V2_inferencing.zip

Ouvrez ce dossier, puis repérez le dossier de la librairie à installer.

### 2. Copier la librairie

Sélectionnez le dossier complet de la librairie, puis copiez-le.

Il est important de copier le dossier entier de la librairie, et non uniquement les fichiers qu’il contient.

### 3. Coller la librairie dans le dossier Arduino

Vous devez maintenant coller ce dossier dans le répertoire des librairies Arduino.

Par défaut, le chemin du dossier est généralement le suivant :

Sur Windows

Documents\Arduino\libraries

Chemin complet le plus courant :

C:\Users\VotreNomUtilisateur\Documents\Arduino\libraries

Sur macOS

Documents/Arduino/libraries

Chemin complet le plus courant :

/Users/VotreNomUtilisateur/Documents/Arduino/libraries

Sur Linux

Arduino/libraries

Chemin complet le plus courant :

/home/VotreNomUtilisateur/Arduino/libraries

Décompresser le dossier

vous pouvez décompresser le dossier dans le dossier libraries, et supprimer le fichier .zip

### 4. Vérifier l’installation

Une fois le dossier de la librairie copié dans le dossier libraries, redémarrez Arduino IDE.

Pour vérifier que la librairie est bien reconnue :

1. Ouvrez Arduino IDE.
2. Cliquez sur le menu Sketch.
3. Allez dans Include Library.
4. Vérifiez que le nom de la librairie apparaît dans la liste.

Si la librairie apparaît dans cette liste, elle est correctement installée et prête à être utilisée dans le projet.

Il faudras repeter la meme demarche pour le fichier Hornets_lib_3.zip

## Installation des librairies Arduino nécessaires

### 1. Présentation

Avant de téléverser le programme sur la carte, certaines librairies doivent être installées dans Arduino IDE.

Les librairies permettent d’ajouter des fonctionnalités au programme, par exemple gérer une caméra, lire un capteur de température ou communiquer avec un capteur de luminosité.

### 2. Liste des librairies utilisées

Le programme utilise les librairies suivantes :

#include <Arduino.h>

#include "esp_camera.h"

#include <ctype.h>

#include <string.h>

#include <DHT.h>

#include <BH1750.h>

#include <Wire.h>

Voici le détail des librairies nécessaires :

Librairie | Utilité | Installation nécessaire
Arduino .h | Librairie de base d’Arduino | Non, incluse avec Arduino IDE
esp_cam era.h | Gestion de la caméra ESP32-CAM | Non, incluse avec le support de carte ESP32
ctype.h | Fonctions de traitement de caractères | Non, incluse par défaut
string. h | Fonctions de manipulation de chaînes de caractères | Non, incluse par défaut
DHT.h | Gestion du capteur DHT | Oui
BH1750. h | Gestion du capteur de luminosité BH1750 | Oui
Wire.h | Communication I2C entre la carte et certains capteurs | Non, incluse avec Arduino IDE

### 3. Installer les librairies depuis Arduino IDE

Les librairies DHT.h et BH1750.h doivent être installées manuellement depuis le gestionnaire de librairies Arduino.

Pour cela :

1. Ouvrez Arduino IDE.
2. Cliquez sur le menu Sketch.
3. Allez dans Include Library.
4. Cliquez sur Manage Libraries….
5. Dans la barre de recherche, recherchez la librairie à installer.
6. Sélectionnez la librairie correspondante.
7. Cliquez sur Install.

### 4. Librairie DHT

Dans le gestionnaire de librairies, recherchez :

DHT sensor library

Installez la librairie DHT sensor library.

Arduino IDE peut proposer d’installer des dépendances supplémentaires. Dans ce cas, acceptez leur installation.

### 5. Librairie BH1750

Dans le gestionnaire de librairies, recherchez :

BH1750

Installez la librairie BH1750.

### 6. Support de carte ESP32

La librairie esp_camera.h est disponible uniquement si le support des cartes ESP32 est installé dans Arduino IDE.

Si ce n’est pas encore fait, il faut installer le support ESP32 depuis le gestionnaire de cartes.

Pour cela :

1. Ouvrez Arduino IDE.
2. Cliquez sur File puis Preferences.
3. Dans le champ Additional Boards Manager URLs, ajoutez l’URL du gestionnaire de cartes ESP32.
4. Cliquez sur OK.
5. Allez ensuite dans Tools.
6. Cliquez sur Board, puis Boards Manager.
7. Recherchez ESP32.
8. Installez le package esp32.

Une fois le support ESP32 installé, la librairie esp_camera.h sera disponible automatiquement.

### 7. Vérifier l’installation

Après l’installation des librairies, redémarrez Arduino IDE.

Pour vérifier qu’une librairie est bien installée :

1. Cliquez sur Sketch.
2. Allez dans Include Library.
3. Vérifiez que les librairies installées apparaissent dans la liste.

Vous pouvez ensuite ouvrir le programme et lancer une vérification en cliquant sur le bouton Verify.

Si aucune erreur de librairie manquante n’apparaît, l’installation est correcte.

## Configuration de TTN pour recevoir les données du module LoRaWAN E5

### 1. Présentation

Pour recevoir les données envoyées par le module LoRaWAN E5, il est nécessaire d’utiliser une plateforme réseau LoRaWAN.

Dans ce projet, la plateforme utilisée est TTN, aussi appelée The Things Network.
TTN permet de connecter un appareil LoRaWAN à Internet afin de visualiser les données envoyées par le module.

Concrètement, le fonctionnement est le suivant :

Module LoRaWAN E5 → Passerelle LoRaWAN → TTN → Visualisation des données

Le module LoRaWAN E5 envoie les données par radio.
Une passerelle LoRaWAN à proximité reçoit ces données, puis les transmet à TTN via Internet.

## 2. Prérequis

Avant de commencer, assurez-vous d’avoir :

- un compte TTN ;
- un module LoRaWAN E5 configuré ;
- une passerelle LoRaWAN disponible à proximité ;
- les identifiants LoRaWAN du module :
- DevEUI ;

- JoinEUI, aussi appelé AppEUI ;
- AppKey ;
- la bonne région radio, par exemple Europe 863-870 MHz pour la France.

Le module et la passerelle doivent utiliser le même plan de fréquence pour pouvoir communiquer correctement. TTN précise également que les appareils sont gérés dans des Applications, qui servent à regrouper les objets LoRaWAN par projet ou par usage.

## 3. Créer un compte TTN

Rendez-vous sur le site de TTN :

https://www.thethingsnetwork.org/

Cliquez sur Sign up ou Get started afin de créer un compte.

Une fois le compte créé, connectez-vous à la console TTN.
Pour la version communautaire de The Things Stack Sandbox, la console est disponible à l’adresse suivante :

https://console.cloud.thethings.network/

La documentation officielle indique que The Things Stack Sandbox utilise l’adresse cloud.thethings.network pour accéder à la console.

## 4. Créer une application

Une fois connecté à la console TTN :

1. Cliquez sur Applications.
2. Cliquez sur Create application.
3. Renseignez un nom pour l’application.

Exemple :

iabeille-application

4. Ajoutez une description si nécessaire.
5. Cliquez sur Create application.

L’application sert à regrouper les appareils LoRaWAN du projet.
C’est dans cette application que le module LoRaWAN E5 sera ajouté.

## 5. Ajouter le module LoRaWAN E5 dans TTN

Dans l’application que vous venez de créer :

1. Allez dans le menu End devices.

2. Cliquez sur Register end device.

TTN propose plusieurs méthodes d’ajout.
Dans le cas d’un module LoRaWAN E5 configuré manuellement, choisissez généralement :

Enter end device specifics manually

La documentation TTN recommande cette méthode lorsque l’appareil n’est pas ajouté automatiquement depuis le catalogue de périphériques ou lorsque l’on souhaite renseigner les paramètres manuellement.

## 6. Renseigner les informations du module

Vous devez maintenant compléter les informations du module.

Plan de fréquence

Pour une utilisation en France ou en Europe, sélectionnez généralement :

Europe 863-870 MHz

Attention : le plan de fréquence doit correspondre à celui utilisé par le module LoRaWAN E5 et par la passerelle LoRaWAN.

Version LoRaWAN

Sélectionnez la version LoRaWAN utilisée par votre module.

Exemple courant :

LoRaWAN Specification 1.0.2

ou :

LoRaWAN Specification 1.0.3

La version exacte dépend de la configuration du module LoRaWAN E5.

Activation mode

Choisissez le mode d’activation :

OTAA

OTAA signifie Over-The-Air Activation.
C’est la méthode recommandée, car elle permet au module de rejoindre le réseau de manière sécurisée.

TTN indique que l’activation OTAA est la méthode sécurisée et évolutive pour activer des appareils LoRaWAN.

## 7. Renseigner les identifiants LoRaWAN

Pour que TTN reconnaisse le module, vous devez renseigner les identifiants suivants.

DevEUI

Le DevEUI est l’identifiant unique du module LoRaWAN.

Exemple :

70B3D57ED0000001

JoinEUI / AppEUI

Le JoinEUI, parfois appelé AppEUI, identifie l’application ou le serveur de jointure.

Exemple :

0000000000000000

AppKey

L’AppKey est une clé de sécurité utilisée lors de l’activation OTAA.

Exemple :

00112233445566778899AABBCCDDEEFF

Ces valeurs doivent être identiques à celles configurées dans le programme du module LoRaWAN E5.
Si une seule valeur est différente, le module ne pourra pas rejoindre le réseau TTN.

## 8. Finaliser l’ajout de l’appareil

Une fois les informations renseignées :

1. Donnez un nom à l’appareil dans le champ End device ID.

Exemple :

iabeille-lorawan-e5

2. Vérifiez toutes les informations.
3. Cliquez sur Register end device.

Le module LoRaWAN E5 est maintenant enregistré dans TTN.

## 9. Vérifier la réception des données

Après l’enregistrement du module :

1. Ouvrez votre application TTN.
2. Cliquez sur End devices.
3. Sélectionnez votre module LoRaWAN E5.
4. Ouvrez l’onglet Live data.

Lorsque le module envoie des données, elles doivent apparaître dans cette page.

Vous pouvez y voir notamment :

- les tentatives de connexion au réseau ;
- les messages de type Join request ;
- les messages de type Join accept ;
- les données reçues, appelées uplinks ;
- le contenu brut envoyé par le module.

Un appareil apparaît comme connecté dans The Things Stack lorsqu’il envoie un uplink après son enregistrement.

## 10. Comprendre les données reçues

Les données envoyées par le module apparaissent généralement sous forme de valeur brute, souvent encodée en hexadécimal ou en Base64.

Exemple :

{

"frm_payload": "AQIDBA=="

}

Cette valeur correspond aux données envoyées par le module.
Pour les rendre lisibles, il peut être nécessaire d’ajouter un Payload formatter dans TTN.

## 11. Ajouter un décodeur de données

Pour transformer les données brutes en valeurs compréhensibles, vous pouvez utiliser un Payload formatter.

Dans TTN :

1. Ouvrez votre application.
2. Cliquez sur Payload formatters.
3. Sélectionnez Uplink.

4. Choisissez le format Javascript formatter.
5. Copier coller le contenue du fichier Payload formateur : IAbeille/src/payload formateur
6. Cliquez sur Save changes.

## 12. Problèmes fréquents

Aucune donnée n’apparaît dans TTN

Vérifiez que :

- Le module LoRaWAN E5 est bien alimenté ;
- Une passerelle LoRaWAN est disponible à proximité ;
- Le module utilise le bon plan de fréquence ;
- Le DevEUI, le JoinEUI et l’AppKey sont corrects ;
- Le mode d’activation est bien OTAA ;
- Le programme du module envoie bien des données.

Le module n’arrive pas à rejoindre le réseau

Vérifiez les messages dans l’onglet Live data.
Si vous voyez des erreurs de type Join failed, le problème vient souvent d’une clé incorrecte, d’une mauvaise région radio ou d’une version LoRaWAN mal configurée.

TTN avertit qu’un mauvais choix de version LoRaWAN peut provoquer des erreurs complexes : l’activation peut fonctionner, mais la communication peut ensuite être instable.

Les données sont illisibles

Si les données apparaissent sous forme brute, cela signifie qu’il manque probablement un décodeur de payload.

Dans ce cas, ajoutez ou adaptez le Payload formatter afin de convertir les données reçues en valeurs lisibles.

## 13. Résultat attendu

Une fois la configuration terminée, TTN doit afficher les messages envoyés par le module LoRaWAN E5 dans l’onglet Live data.

L’utilisateur peut alors vérifier que les données sont bien reçues et suivre les valeurs transmises par le projet.

## Configuration de Bleep pour visualiser les données

## 1. Configuration du Compte et du Rucher

Avant de poser vos capteurs, vous devez créer votre environnement.

- Inscription : Rendez-vous sur app.beep.nl et créez votre compte.
- Création du rucher : Allez dans l'onglet "Ruchers"
- Ajoutez un nouveau rucher en précisant le nom et la localisation géographique (utile pour les prévisions météo intégrées).
- Ajout des ruches : * Dans votre rucher, créez chaque ruche individuellement.
- Configurez le type de ruche (Dadant, Langstroth, etc.) pour que l'algorithme de calcul du poids soit plus précis.
- Ajouter des capteurs : Aller dans l’onglet Appareils
- Ajoutez un système en cliquant sur “Ajouter votre appareil”.
- Configurez les informations que vous allez récupérer par vos capteurs (Exemple : t pour température) puis cliquez sur le logo validé pour chaque capteur ajouté.

Rattachez votre appareil à une ruche en sélectionnant other dans le champ tapez puis sélectionner la ruche dans le champ ruche.

## 2. Connection de BEEP avec TTN

Une fois l’appareil créé, un code est créé à son tour dans le champ “identifiant unique de l’appareil”. Ce code va permettre en allant sur le payload formatter de TTN d’identifier l’appareil lors de l’envoie des données. Pour se faire il suffit de changer dans le champ “data.key = “...” ” les “…” par le code de l’appareil.
Par ailleurs, il faudra créer un webhook qui sera le lien entre TTN et BEEP. Pour cela il faut se rendre dans l’onglet Webhook de TTN, puis cliquer sur add webhook et enfin cliquer sur custom webhook. Cela va vous diriger sur une page où il suffira de rentrer le nom que vous souhaitez dans le champ “ Webhook ID”, de mettre le lien suivant dans “Base URL” : https://beep-test.azurewebsites.net/api/yann et enfin cliquer sur Uplink message afin de l’activer.

## 3. Résultat attendu

Une fois cette configuration terminée, il ne vous reste plus qu’à attendre un envoi de votre système sur TTN pour pouvoir afficher les données dans l’outil inspection de BEEP lié à la ruche.

# 7. implémentation logiciel

## Téléverser un code sur une carte avec Arduino IDE

### 1. Présentation

Une fois Arduino IDE installé et les bibliothèques nécessaires ajoutées, il faut envoyer le programme sur la carte.

Cette opération s’appelle le téléversement ou le flashage.
Elle permet de transférer le code depuis l’ordinateur vers la carte Arduino ou compatible.

## 2. Ouvrir le projet dans Arduino IDE

Commencez par ouvrir le fichier principal du programme.

1. Lancez Arduino IDE.
2. Cliquez sur File.
3. Cliquez sur Open.
4. Sélectionnez le fichier du projet.

Le fichier à ouvrir possède généralement l’extension suivante :

.ino

choisissez le code

COM_N_AI.ino

Une fois le fichier ouvert, le code du programme apparaît dans Arduino IDE.

## 3. Brancher la carte à l’ordinateur

Branchez la carte XIAO à l’ordinateur à l’aide d’un câble USB.

Il est recommandé d’utiliser un câble USB permettant le transfert de données.
Certains câbles USB servent uniquement à la recharge et ne permettent pas de communiquer avec la carte.

Lorsque la carte est correctement branchée, une LED s’allume généralement sur celle-ci.

## 4. Sélectionner le type de carte

Arduino IDE doit savoir quel type de carte est utilisé.

Pour sélectionner la carte :

1. Cliquez sur le menu Tools.
2. Allez dans Board.
3. Sélectionnez le modèle correspondant à votre carte.

XIAO ESP32S3

Le choix de la carte est important.
Si le mauvais modèle est sélectionné, le code peut ne pas se téléverser correctement ou ne pas fonctionner comme prévu.

Si la carte n’est pas déjà installé :

1. Cliquez sur le menu Board managers
2. Recherchez la carte ESP32 by Espressif Systems
3. installez la carte

## 5. Sélectionner le port USB

Il faut ensuite sélectionner le port sur lequel la carte est connectée.

1. Cliquez sur le menu Tools.
2. Allez dans Port.
3. Sélectionnez le port correspondant à la carte.

Exemples de ports possibles :

Sur Windows
COM3
COM4
COM5

Sur macOS ou Linux
/dev/ttyUSB0
/dev/ttyACM0
/dev/cu.usbserial

Si plusieurs ports sont affichés, débranchez la carte puis rebranchez-la.
Le port qui apparaît après le branchement est généralement celui de la carte.

## 6. Vérifier le code

Avant d’envoyer le programme sur la carte, il est conseillé de vérifier que le code ne contient pas d’erreur.

Pour cela, cliquez sur le bouton Verify.

Ce bouton est représenté par une icône en forme de coche :

✓

Arduino IDE va alors compiler le programme.

Si tout est correct, un message similaire apparaît en bas de la fenêtre :

Compilation done.

ou :

Done compiling.

Si une erreur apparaît, le téléversement ne pourra pas être effectué. Il faut alors corriger l’erreur indiquée avant de continuer.

## 7. Téléverser le code sur la carte

Une fois le code vérifié, vous pouvez l’envoyer sur la carte.

Cliquez sur le bouton Upload.

Ce bouton est représenté par une flèche vers la droite :

→

Arduino IDE compile à nouveau le programme, puis le transfère vers la carte.

Pendant cette étape, il ne faut pas débrancher la carte.

Lorsque le téléversement est terminé, un message apparaît en bas de la fenêtre :

Upload done.

ou :

Done uploading.

Le programme est maintenant installé sur la carte.

## 9. Vérifier le fonctionnement du programme

Le moniteur série permet d’afficher les messages envoyés par la carte vers l’ordinateur. Il est très utile pour vérifier que le programme fonctionne correctement.

Pour l’ouvrir :

1. Cliquez sur Tools.
2. Cliquez sur Serial Monitor.

Vous pouvez aussi utiliser l’icône du moniteur série en haut à droite d’Arduino IDE.

Une fois le moniteur série ouvert, vérifiez que la vitesse de communication est correcte.

La vitesse la plus courante est :

9600 baud

Cependant, certains programmes utilisent une autre vitesse, par exemple :

115200 baud

La vitesse sélectionnée dans le moniteur série doit correspondre à celle indiquée dans le code avec la ligne :

Serial.begin(9600);

ou :

Serial.begin(115200);

Résultat attendu

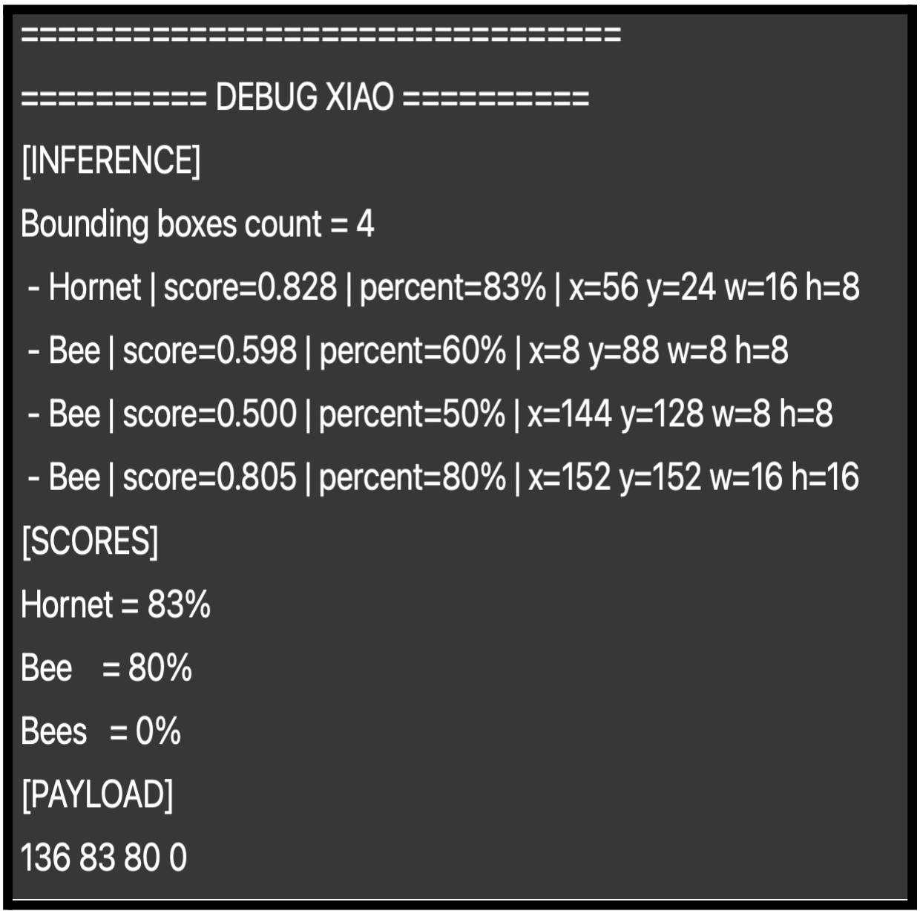
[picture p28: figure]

Dans cet exemple, une détection à été réalisée. Si vous ne voyez pas de “bounding boxes” et des scores à 0 c’est normal.

## 10. Problèmes fréquents

La carte n’apparaît pas dans les ports

Vérifiez que :

- le câble USB permet bien le transfert de données ;
- la carte est correctement branchée ;
- le pilote USB de la carte est installé ;
- Arduino IDE a été redémarré après le branchement.

Le téléversement échoue

Vérifiez que :

- Le bon type de carte est sélectionné ;
- Le bon port USB est sélectionné ;
- Aucune autre application n’utilise le port série ;
- Le câble USB fonctionne correctement ;
- Les bibliothèques nécessaires sont bien installées.

## 11. Résultat attendu

À la fin de cette étape, le programme est correctement envoyé sur la carte.

La carte peut maintenant fonctionner de manière autonome avec le code installé.
Elle exécutera automatiquement ce programme à chaque démarrage ou à chaque remise sous tension.

# 8. Intégration

### 1. Connecter les composants

Avant de mettre le dispositif sous tension, vérifiez que toutes les cartes électroniques et tous les composants sont correctement connectés aux emplacements prévus.

Assurez-vous notamment que :

- les cartes sont bien insérées ;
- les connecteurs sont correctement branchés ;
- aucun câble n’est débranché ou mal positionné ;
- la batterie est connectée ;
- les capteurs sont reliés aux bons emplacements.

Cette vérification permet d’éviter un mauvais fonctionnement du système lors du premier démarrage.

## 2. Allumer le dispositif

Une fois les branchements vérifiés, allumez le dispositif à l’aide du bouton On/Off.

Au démarrage, le système doit émettre un son avec le buzzer pendant environ :

0,5 seconde

Ce signal sonore indique que le dispositif est bien alimenté et que le programme démarre correctement.

## 3. Vérifier la recharge de la batterie

Après l’allumage du dispositif, vérifiez que la batterie est correctement prise en charge par le module de recharge.

Pour cela, observez la LED présente sur la carte LiPo DFR0264.

Si la LED de la carte s’allume, cela indique que le module détecte la batterie et que le circuit de recharge fonctionne correctement.

## 4. Vérifier la réception des données

Une fois le dispositif allumé, les données doivent être transmises automatiquement.

Vous devez vérifier que les informations sont bien reçues sur les plateformes prévues :

TTN
Bleep

Vérification sur TTN

Connectez-vous à votre compte The Things Network.

Dans l’application correspondant au projet, ouvrez l’onglet Live data de votre appareil.

Vous devez voir apparaître les messages envoyés par le dispositif.

Vérification sur Bleep

Connectez-vous à la plateforme Bleep utilisée pour le projet.

Vérifiez que les données du dispositif sont bien visibles et qu’elles se mettent à jour correctement.

## 5. Valider le fonctionnement complet du système

Avant d’installer le dispositif sur la ruche, assurez-vous que l’ensemble du système fonctionne correctement.

Les points suivants doivent être validés :

- le dispositif s’allume correctement ;
- le buzzer émet bien un son au démarrage ;
- la batterie est détectée et peut se recharger ;

- les données sont reçues sur TTN ;
- les données sont reçues sur Bleep ;
- aucun câble ou composant ne semble mal connecté.

Cette étape est importante afin de s’assurer que le dispositif est opérationnel avant son installation définitive.

## 6. Fixer le système à la ruche

Une fois toutes les vérifications terminées et le fonctionnement validé, vous pouvez fixer le dispositif à la ruche.

Veillez à installer le système de manière stable et sécurisée, afin qu’il reste bien en place pendant son utilisation.

Le dispositif est maintenant prêt à fonctionner sur la ruche.

# 9. remerciements

Nous tenons à remercier l’ensemble des personnes ayant contribué à la réalisation du projet IABEILLES.

Nous remercions tout particulièrement nos trois encadrants pour leur accompagnement, leurs conseils et leur disponibilité tout au long du projet :

- Mr Yann Douze, professeur d’IoT, pour son expertise, ses conseils sur l’architecture et son accompagnement dans les choix techniques.
- Mme Sophie myszkinski, professeur de management, pour son aide dans l’organisation du projet, la gestion du travail en équipe et la structuration de notre démarche.
- Mr Sylvain Viateur, ingénieur support technique, pour ses conseils lors de la conception, des tests, du prototypage et le troubleshooting.

Nous les remercions sincèrement pour le temps accordé, les retours constructifs et le soutien apporté tout au long du développement de ce projet.

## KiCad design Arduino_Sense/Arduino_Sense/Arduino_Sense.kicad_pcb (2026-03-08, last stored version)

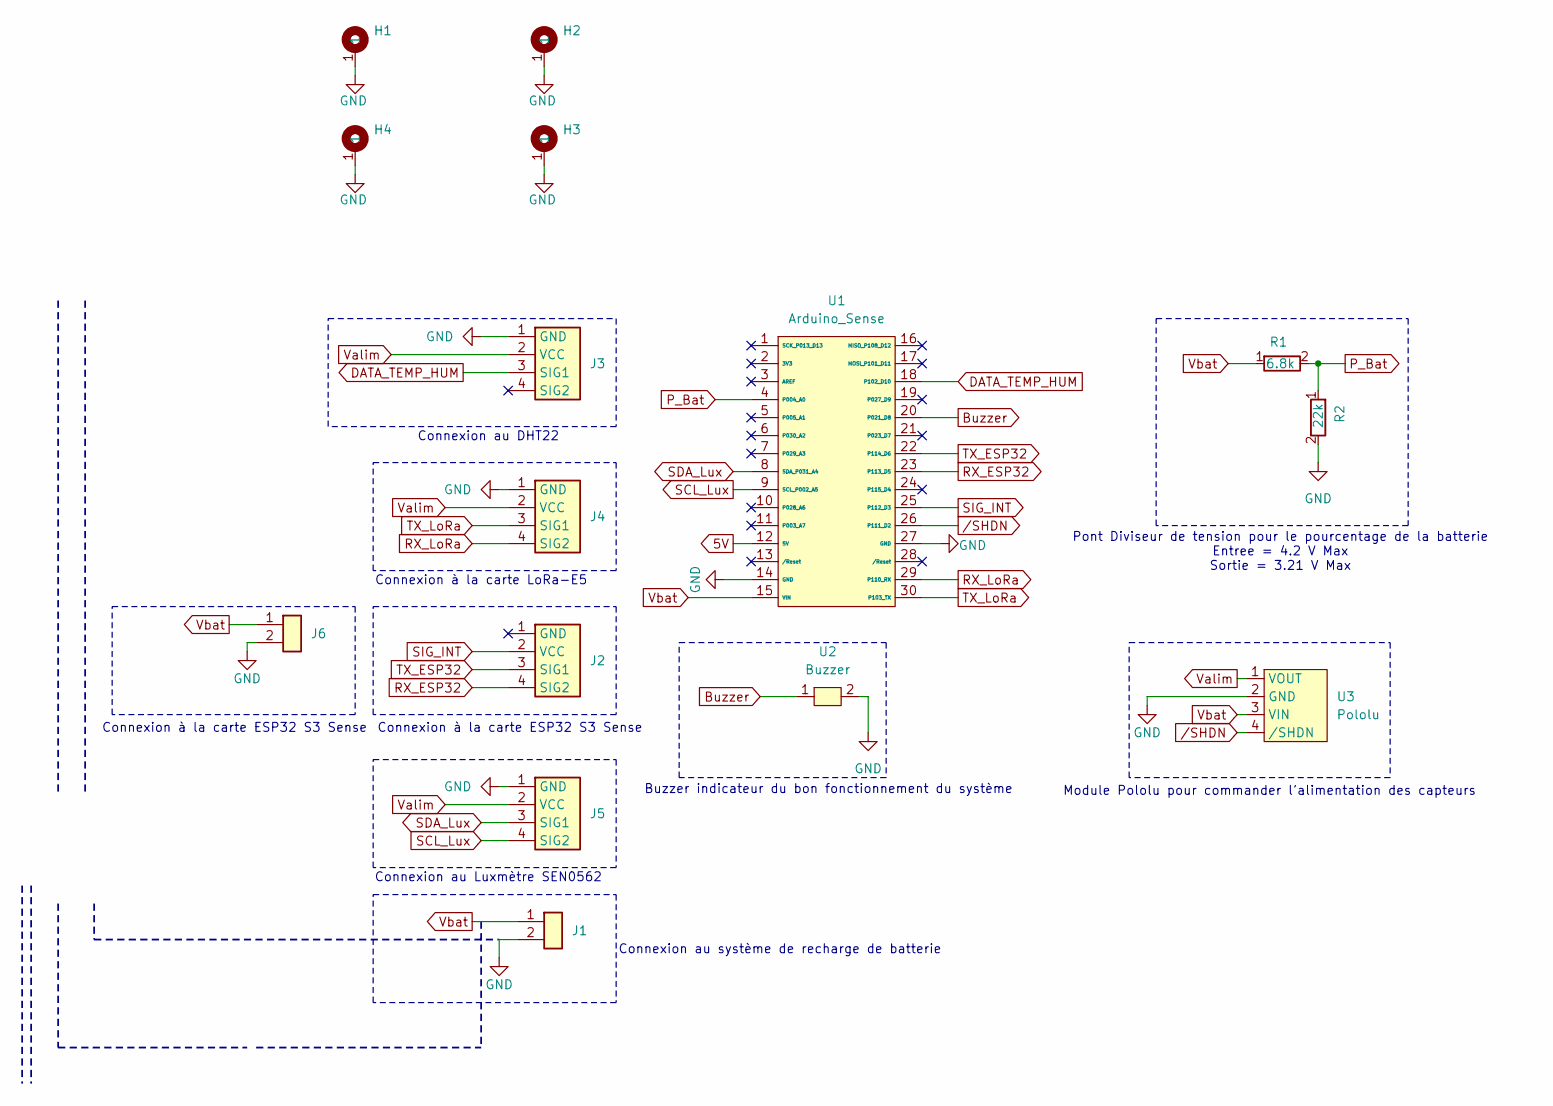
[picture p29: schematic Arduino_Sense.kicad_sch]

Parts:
H1, H2, H3, H4: Mounting_Hole
J1, J6: PinSocket_1x02_P2.00mm_Vertical
J2, J3, J4, J5: PinSocket_1x04_P2.00mm_Vertical
R1: 6.8k; R
R2: 22k; R
U1: Arduino_Sense
U2: Buzzer
U3: Pololu

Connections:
5V: U1.12 (5V)
Buzzer: U1.20 (P021_D8), U2.1
DATA_TEMP_HUM: J3.3 (SIG1), U1.18 (P102_D10)
GND: H1.1, H2.1, H3.1, H4.1, J1.2, J3.1 (GND), J4.1 (GND), J5.1 (GND), J6.2, R2.2, U1.14 (GND), U1.27 (GND), U2.2, U3.2 (GND)
P_Bat: R1.2, R2.1, U1.4 (P004_A0)
RX_ESP32: J2.4 (SIG2), U1.23 (P113_D5)
RX_LoRa: J4.4 (SIG2), U1.29 (P110_RX)
SCL_Lux: J5.4 (SIG2), U1.9 (SCL_P002_A5)
SDA_Lux: J5.3 (SIG1), U1.8 (SDA_P031_A4)
SIG_INT: J2.2 (VCC), U1.25 (P112_D3)
TX_ESP32: J2.3 (SIG1), U1.22 (P114_D6)
TX_LoRa: J4.3 (SIG1), U1.30 (P103_TX)
Valim: J3.2 (VCC), J4.2 (VCC), J5.2 (VCC), U3.1 (VOUT)
Vbat: J1.1, J6.1, R1.1, U1.15 (VIN), U3.3 (VIN)
/SHDN: U1.26 (P111_D2), U3.4 (/SHDN)

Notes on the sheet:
Connexion à la carte ESP32 S3 Sense
Connexion au Luxmètre SEN0562
Buzzer indicateur du bon fonctionnement du système
Connexion à la carte ESP32 S3 Sense
Pont Diviseur de tension pour le pourcentage de la batterie Entree = 4.2 V Max Sortie = 3.21 V Max
Connexion au DHT22
Connexion à la carte LoRa-E5
Module Pololu pour commander l'alimentation des capteurs
Connexion au système de recharge de batterie

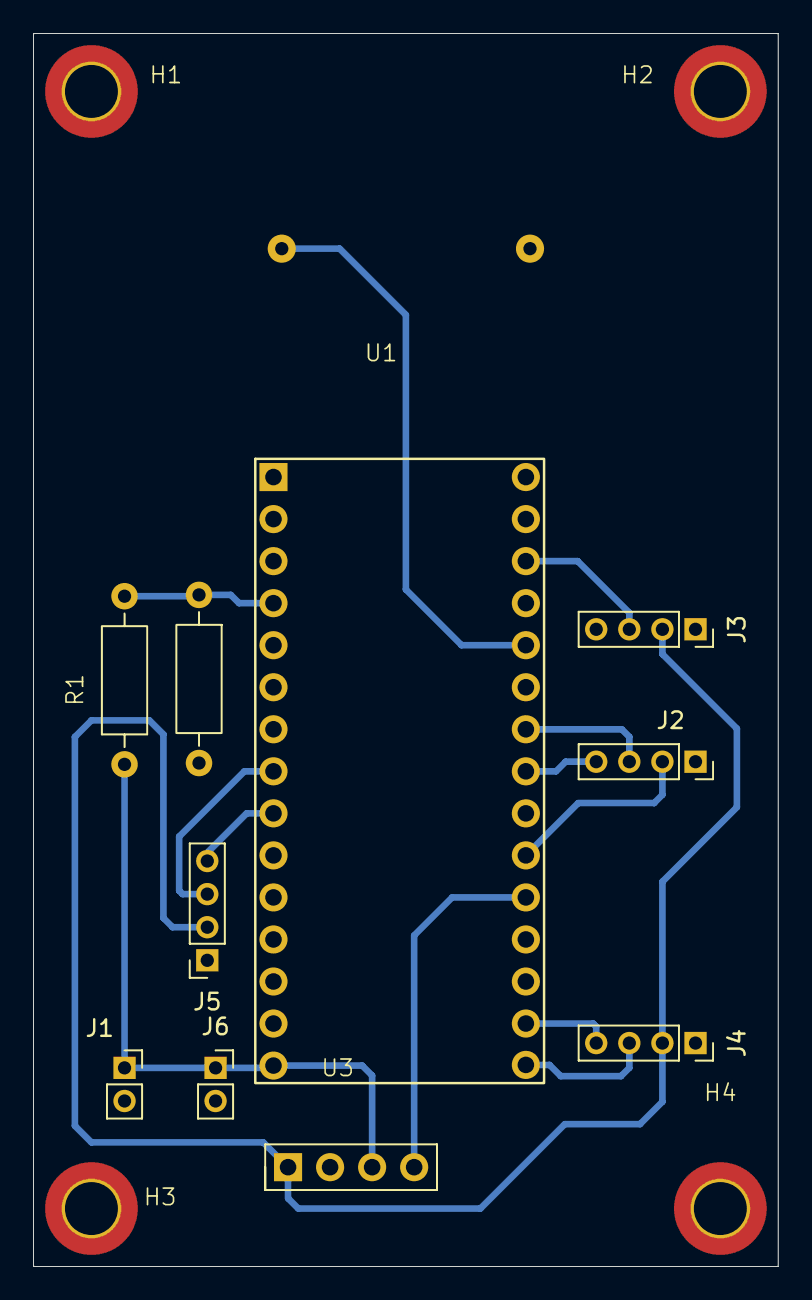
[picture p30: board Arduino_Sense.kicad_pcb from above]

Board: 2 copper layers, 45.0 x 74.5 mm, 15 parts (0 on the bottom side), 14 nets.

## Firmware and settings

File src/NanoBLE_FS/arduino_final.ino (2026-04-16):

#include <Arduino.h>
#include <mbed.h>
#include <chrono>
#include <DHT.h>
#include <BH1750.h>
#include <Wire.h>
#include "HornetAudio.h"

#define DEBUG 0

#if DEBUG
#define DEBUG_PRINT(x) Serial.print(x)
#define DEBUG_PRINTLN(x) Serial.println(x)
#define DEBUG_BEGIN(x) \
  Serial.begin(x); \
  while (!Serial) \
    ;
#else
#define DEBUG_PRINT(x)
#define DEBUG_PRINTLN(x)
#define DEBUG_BEGIN(x)
#endif

// =====================
// Arduino Nano 33 BLE
// Bit-bang UART
// RX = D5
// TX = D6
// WAKE OUT = D3
// Buzzer = D8
// DHT22 DATA = D10
// LoRaWAN module = Serial1
// =====================

// ------- AI Output --------
float lastTemp = NAN;
float lastHum = NAN;

int comptForceCam = 0;

uint8_t lastBatteryStatus = 0;
uint16_t lastLux = 0;

uint8_t lastHornet_sound = 0;  // Sera utilisé pour t_5
uint8_t lastQueen_sound = 0;   // Sera utilisé pour t_4
uint8_t lastHornet = 0;        // Sera utilisé pour t_1
uint8_t lastBee = 0;           // Sera utilisé pour t_2
uint8_t lastBees = 0;          // Sera utilisé pour t_3
uint8_t lastStatus = 0;        // Sera utilisé pour t_0 (0-3)

// ---------- Downlink ----------
// 0: Mode IA (Détection frelon), 1: 30 mins, 2: 2 mins (Test)
uint8_t modeFonctionnement = 0;
unsigned long intervalleEnvoi = 0;  // ms
unsigned long dernierEnvoiLoRa = 0;
int rssiJoin = 0;

// ---------- Bit-bang UART ----------
static const int PIN_RX = D5;
static const int PIN_TX = D6;
static const int PIN_WAKE_OUT = D3;
static const int PIN_SHDN = D2;

// ---------- Buzzer ----------
static const int PIN_BUZZER = D8;
static const int DELAY_BUZZER = 1000;

// ---------- DHT22 ----------
static const int PIN_DHT = D10;
#define DHTTYPE DHT22
DHT dht(PIN_DHT, DHTTYPE);

// ---------- BH1750 ----------
BH1750 lightMeter;

// ---------- Configuration Batterie ----------
const int PIN_BATTERY = A0;
const float R1 = 6800.0;
const float R2 = 22000.0;
const float BAT_RATIO = (R1 + R2) / R2;

const float VOLT_MAX = 4.20;  // 100%
const float VOLT_MIN = 3.30;  // 0%

int cyclesSansEnvoi = 0;
int MAX_CYCLES_SILENCE = 60;

// ---------- LoRaWAN ----------
const char *DevEUI = "70B3D57ED00761C6";
const char *appEui = "0000000000000000";
const char *appKey = "73D3232B6CA32A68C5695B8DCC3E4672";

// ---------- Machine à États ----------
enum EtatSysteme {
  ETAT_SOMMEIL,
  ETAT_VERIFICATION,
  ETAT_ANALYSE_AUDIO,
  ETAT_ANALYSE_CAMERA,
  ETAT_ENVOI_LORAWAN
};

EtatSysteme etatActuel = ETAT_SOMMEIL;
int compteurSommeil = 0;
uint8_t request_id = 1;

// ---------- Fonctions d'énergie ----------

void entrerModeSommeil(uint32_t dureeMs) {
  Wire.begin();  // S'assurer que le bus est prêt pour envoyer les ordres d'extinction
  // 1. Éteindre le BH1750 (Lumière) manuellement via I2C
  // L'adresse par défaut est souvent 0x23. La commande Power Down est 0x00.
  Wire.beginTransmission(0x23);
  Wire.write(0x00);
  Wire.endTransmission();

  // 2. Éteindre les autres capteurs internes (ton code existant)
  writeI2C(0x6B, 0x10, 0x00);  // IMU
  writeI2C(0x6B, 0x20, 0x00);
  writeI2C(0x1E, 0x22, 0x03);  // Magneto
  writeI2C(0x39, 0x80, 0x00);  // Proximité
  writeI2C(0x5F, 0x20, 0x00);  // Humidité/Temp interne
  writeI2C(0x5C, 0x10, 0x00);  // Baromètre

  // 3. Arrêter le Micro PDM et le bit-bang DHT
  PDM.end();
  pinMode(PIN_DHT, INPUT);  // On "libère" la pin du DHT22 pour éviter les fuites

  // 4. Couper le régulateur Pololu (LoRa/Caméra)
  digitalWrite(PIN_SHDN, LOW);

  // 5. Désactiver la LED (si applicable)
  digitalWrite(LED_PWR, LOW);

  // 6. Désactiver le bus I2C (Haute impédance)
  pinMode(PIN_WIRE_SDA, INPUT);
  pinMode(PIN_WIRE_SCL, INPUT);
  // 7. Sommeil
  rtos::ThisThread::sleep_for(std::chrono::milliseconds(dureeMs));
}

// Fonction utilitaire légère pour écrire dans les registres
void writeI2C(uint8_t address, uint8_t reg, uint8_t data) {
  Wire.beginTransmission(address);
  Wire.write(reg);
  Wire.write(data);
  Wire.endTransmission();
}

void reveillerCapteurs() {

  Wire.begin();
  dht.begin();
  lightMeter.begin(BH1750::CONTINUOUS_HIGH_RES_MODE);
  digitalWrite(PIN_SHDN, HIGH);
  delay(10);
  if (!PDM.begin(1, 16000)) {
    DEBUG_PRINTLN("Échec démarrage PDM");
  }

  //digitalWrite(LED_PWR,LOW);

#if DEBUG
  Serial.begin(9600);
#endif
}

void checkDownlink() {
  if (Serial1.available()) {
    String line = Serial1.readStringUntil('\n');
    DEBUG_PRINT("[LoRa RX] : ");
    DEBUG_PRINTLN(line);

    // --- 1. Extraction du RSSI ---
    if (line.indexOf("RSSI") != -1) {
      int posRSSI = line.indexOf("RSSI");
      int posComma = line.indexOf(",", posRSSI);
      if (posComma != -1) {
        String val = line.substring(posRSSI + 5, posComma);
        val.trim();
        rssiJoin = val.toInt();
        DEBUG_PRINT("=> RSSI capturé via Downlink : ");
        DEBUG_PRINTLN(rssiJoin);
      }
    }

    // --- 2. Gestion des commandes (ton code actuel) ---
    int posRX = line.indexOf("RX:");
    if (posRX >= 0) {
      String hexVal = line.substring(posRX + 3);
      hexVal.trim();
      hexVal.replace("\"", "");
      int commande = (int)strtol(hexVal.c_str(), NULL, 16);

      switch (commande) {
        case 0: modeFonctionnement = 0; break;
        case 1:
          modeFonctionnement = 1;
          intervalleEnvoi = 30 * 60 * 1000;
          break;
        case 2:
          modeFonctionnement = 2;
          intervalleEnvoi = 2 * 60 * 1000;
          break;
      }
    }
  }
}

void updateBatteryStatus() {
  long sumRaw = 0;
  for (int i = 0; i < 20; i++) {
    sumRaw += analogRead(PIN_BATTERY);
    delayMicroseconds(500);
  }

  float averageRaw = sumRaw / 20.0;
  float voltageA0 = (averageRaw * 3.3) / 4095.0;
  float batteryVoltage = voltageA0 * BAT_RATIO;

  float percentage = (batteryVoltage - VOLT_MIN) * 100.0 / (VOLT_MAX - VOLT_MIN);
  lastBatteryStatus = (uint8_t)constrain((int)round(percentage), 0, 100);
}

// ---------- UART bit-bang ----------
static const uint32_t BAUD = 4800;
static const uint32_t BIT_US = 1000000UL / BAUD;

enum MsgType : uint8_t {
  CMD_RUN = 0x01,
  RESULT = 0x02,
  ACK = 0x03,
  CMD_SLEEP = 0x04,
  ERROR_MSG = 0x05
};

static inline void bb_wait_bit() {
  delayMicroseconds(BIT_US);
}

uint8_t checksum_xor(const uint8_t *buf, size_t n) {
  uint8_t x = 0;
  for (size_t i = 0; i < n; i++) x ^= buf[i];
  return x;
}

void bb_tx_byte(uint8_t b) {
  noInterrupts();

  digitalWrite(PIN_TX, LOW);
  bb_wait_bit();

  for (int i = 0; i < 8; i++) {
    digitalWrite(PIN_TX, (b & 0x01) ? HIGH : LOW);
    bb_wait_bit();
    b >>= 1;
  }

  digitalWrite(PIN_TX, HIGH);
  bb_wait_bit();

  interrupts();
}

bool bb_rx_byte(uint8_t &out, uint32_t timeout_us = 500000) {
  uint32_t t0 = micros();

  while (digitalRead(PIN_RX) == HIGH) {
    if ((micros() - t0) > timeout_us) return false;
  }

  noInterrupts();

  delayMicroseconds(BIT_US + BIT_US / 2);

  uint8_t b = 0;
  for (int i = 0; i < 8; i++) {
    b |= (digitalRead(PIN_RX) ? 1 : 0) << i;
    delayMicroseconds(BIT_US);
  }

  delayMicroseconds(BIT_US);

  interrupts();

  out = b;
  return true;
}

void send_packet(uint8_t type, const uint8_t *payload, uint8_t len) {
  uint8_t chk = 0;

  bb_tx_byte(0xA5);
  delay(2);
  chk ^= 0xA5;

  bb_tx_byte(0x5A);
  delay(2);
  chk ^= 0x5A;

  bb_tx_byte(type);
  delay(2);
  chk ^= type;

  bb_tx_byte(len);
  delay(2);
  chk ^= len;

  for (uint8_t i = 0; i < len; i++) {
    bb_tx_byte(payload[i]);
    delay(2);
    chk ^= payload[i];
  }

  bb_tx_byte(chk);
  delay(2);
}

bool recv_packet(uint8_t &type, uint8_t *payload, uint8_t &len,
                 uint32_t timeout_us = 1000000) {
  uint8_t b;
  uint8_t chk = 0;

  do {
    if (!bb_rx_byte(b, timeout_us)) return false;
  } while (b != 0xA5);
  chk ^= b;

  if (!bb_rx_byte(b, timeout_us)) return false;
  if (b != 0x5A) return false;
  chk ^= b;

  if (!bb_rx_byte(type, timeout_us)) return false;
  chk ^= type;

  if (!bb_rx_byte(len, timeout_us)) return false;
  chk ^= len;

  if (len > 32) return false;

  for (uint8_t i = 0; i < len; i++) {
    if (!bb_rx_byte(payload[i], timeout_us)) return false;
    chk ^= payload[i];
  }

  uint8_t rx_chk;
  if (!bb_rx_byte(rx_chk, timeout_us)) return false;

  return (chk == rx_chk);
}

// ---------- Capteurs ----------
void printDHT22() {
  float h = dht.readHumidity();
  float t = dht.readTemperature();

  if (isnan(h) || isnan(t)) {
    lastTemp = NAN;
    lastHum = NAN;
    return;
  }

  lastTemp = t;
  lastHum = h;
}

void printLux() {
  float lux = lightMeter.readLightLevel();

  if (lux < 0 || isnan(lux)) {
    lastLux = 0;
    return;
  }

  lastLux = (uint16_t)constrain((int)round(lux), 0, 65535);
}

// // ---------- Commandes XIAO ----------
// void send_cmd_run(uint8_t request_id) {
//   uint8_t payload[1] = { request_id };
//   send_packet(CMD_RUN, payload, 1);
// }

// void send_ack(uint8_t request_id, uint8_t code) {
//   uint8_t payload[2] = { request_id, code };
//   send_packet(ACK, payload, 2);
// }

// void send_cmd_sleep(uint8_t request_id) {
//   uint8_t payload[1] = { request_id };
//   send_packet(CMD_SLEEP, payload, 1);
// }

// ---------- LoRaWAN ----------

bool connectToTTN() {
  while (Serial1.available()) Serial1.read();

  Serial1.print("AT+ID=DevEUI,\"");
  Serial1.print(DevEUI);
  Serial1.println("\"");
  delay(500);

  Serial1.print("AT+ID=AppEUI,\"");
  Serial1.print(appEui);
  Serial1.println("\"");
  delay(500);

  Serial1.print("AT+KEY=APPKEY,\"");
  Serial1.print(appKey);
  Serial1.println("\"");
  delay(500);

  Serial1.println("AT+MODE=LWOTAA");
  delay(500);

  Serial1.println("AT+DR=EU868");
  delay(500);
  /* 0 pour SF12, 5 pour SF7 */
  Serial1.println("AT+DR=0");
  delay(500);

  DEBUG_PRINTLN("Tentative JOIN...");

  unsigned long timeout = millis() + 30000;
  while (millis() < timeout) {
    Serial1.println("AT+JOIN");
    if (Serial1.available()) {
      String line = Serial1.readString();
      DEBUG_PRINT(line);

      if (line.indexOf("joined") != -1) {
        DEBUG_PRINTLN("JOIN réussi");
        return true;
      }
      delay(1000);
    }
  }

  DEBUG_PRINTLN("Timeout JOIN");
  return false;
}

void sendLoRaPayload(const String &payload) {
  //delay(10000);

  DEBUG_PRINT("Envoi payload LoRa : ");
  DEBUG_PRINTLN(payload);

  Serial1.print("AT+MSGHEX=");
  Serial1.println(payload);

  unsigned long start = millis();
  while (millis() - start < 5000) {
    if (Serial1.available()) {
      String resp = Serial1.readString();
      DEBUG_PRINT(resp);
    }
  }
}

String buildLoRaPayload() {
  int16_t temp10 = isnan(lastTemp) ? 0 : (int16_t)round(lastTemp * 10.0);
  uint8_t t0_state = lastStatus;
  uint16_t lux = lastLux;
  uint8_t hum = isnan(lastHum) ? 0 : (uint8_t)constrain((int)round(lastHum), 0, 100);
  uint8_t bv = lastBatteryStatus;
  uint16_t rssi = (uint16_t)(-rssiJoin);
  uint8_t rssi_1 = (uint8_t)((rssi >> 8) & 0xFF);
  uint8_t rssi_2 = (uint8_t)(rssi & 0xFF);

  uint8_t b_t_msb = (uint8_t)((temp10 >> 8) & 0xFF);
  uint8_t b_t_lsb = (uint8_t)(temp10 & 0xFF);

  uint8_t b_l_msb = (uint8_t)((lux >> 8) & 0xFF);
  uint8_t b_l_lsb = (uint8_t)(lux & 0xFF);

  char hexPayload[29];  // 14 octets * 2 chars + null terminator
  sprintf(hexPayload, "%02X%02X%02X%02X%02X%02X%02X%02X%02X%02X%02X%02X%02X%02X",
          b_t_msb, /* t_raw */
          b_t_lsb,
          lastHornet, /*t_1*/
          t0_state,   /*t_0*/
          b_l_msb,    /*l*/
          b_l_lsb,
          hum,              /*h*/
          bv,               /*bv*/
          lastHornet_sound, /*t_2*/
          rssi_1,           /*rssi*/
          rssi_2,
          lastBee,        /*t_3*/
          lastBees,       /*t_4*/
          lastQueen_sound /*t_5*/
  );

  DEBUG_PRINT("Payload construit : ");
  DEBUG_PRINTLN(hexPayload);

  return String(hexPayload);
}

void setup() {

  // usb shut up ble shut up
  DEBUG_BEGIN(115200);
  delay(5000);

  pinMode(LED_PWR, OUTPUT);
  digitalWrite(LED_PWR, LOW);
  //pinMode(PIN_ENABLE_SENSORS_3V3, OUTPUT);
  //pinMode(PIN_ENABLE_I2C_PULLUP, OUTPUT);

  pinMode(PIN_SHDN, OUTPUT);
  digitalWrite(PIN_SHDN, HIGH);

  analogReadResolution(12);

  pinMode(PIN_RX, INPUT_PULLUP);
  pinMode(PIN_TX, OUTPUT);
  digitalWrite(PIN_TX, HIGH);

  pinMode(PIN_WAKE_OUT, OUTPUT);
  digitalWrite(PIN_WAKE_OUT, LOW);

  Wire.begin();
  dht.begin();
  lightMeter.begin(BH1750::CONTINUOUS_HIGH_RES_MODE);

  Serial1.begin(9600);

  pinMode(PIN_BUZZER, OUTPUT);
  digitalWrite(PIN_BUZZER, HIGH);
  delay(DELAY_BUZZER);
  digitalWrite(PIN_BUZZER, LOW);

  DEBUG_PRINTLN("Initialisation terminée");
}

// ---------- Loop ----------
void loop() {
  switch (etatActuel) {

    case ETAT_SOMMEIL:

      if (modeFonctionnement == 2) {
        // mode test : 20 secondes
        entrerModeSommeil(20000);
      } else {
        // modes normaux : 20 mins
        entrerModeSommeil(1200000);
      }

      compteurSommeil++;
      if (compteurSommeil >= 1) {
        compteurSommeil = 0;
        reveillerCapteurs();
        etatActuel = ETAT_VERIFICATION;
      }
      break;

    case ETAT_VERIFICATION:
      updateBatteryStatus();
      /* Sécurité */
      if(lastBatteryStatus<20){
        etatActuel = ETAT_SOMMEIL;
        break;
      }
      printDHT22();
      printLux();

      
      /* Mode jour */
      if (lastTemp > 12.0 && lastLux > 100.0) {

        DEBUG_PRINTLN("-> Mode jour");

        // dans tous les cas remis à zéro dans envoi Lorawan
        cyclesSansEnvoi++;

        // test
        if (modeFonctionnement == 2) {
          DEBUG_PRINTLN("-> Mode test");
          if (cyclesSansEnvoi >= 5) {
            etatActuel = ETAT_ENVOI_LORAWAN;
          }
          else if(comptForceCam >= 2){
            DEBUG_PRINTLN("-> Precision : camera ");
            etatActuel = ETAT_ANALYSE_CAMERA;
          }
          else {
            DEBUG_PRINTLN("-> Precision : audio ");
            etatActuel = ETAT_ANALYSE_AUDIO;
          }
        } else {
          DEBUG_PRINTLN("-> Mode normal");
          if (cyclesSansEnvoi >= 5) {
            etatActuel = ETAT_ENVOI_LORAWAN;
          }
          else if(comptForceCam >= 2){
            DEBUG_PRINTLN("-> Precision : camera ");
            etatActuel = ETAT_ANALYSE_CAMERA;
          }
          else {
            DEBUG_PRINTLN("-> Precision : audio ");
            etatActuel = ETAT_ANALYSE_AUDIO;
          }
        }

      } 
      else {
        DEBUG_PRINTLN("-> Mode nuit");

        cyclesSansEnvoi++;
        if (cyclesSansEnvoi >= 5) {
          lastHornet_sound = 0;  // Sera utilisé pour t_5
          lastQueen_sound = 0;   // Sera utilisé pour t_4
          lastHornet = 0;        // Sera utilisé pour t_1
          lastBee = 0;           // Sera utilisé pour t_2
          lastBees = 0;          // Sera utilisé pour t_3
          lastStatus = 0;        // Sera utilisé pour t_0 (0-3)
          etatActuel = ETAT_ENVOI_LORAWAN;
        }
      }

      break;

    case ETAT_ANALYSE_AUDIO:
      {
        comptForceCam++;

        float probaHornet = -1;
        for (int i = 0; i < 3; i++) {
          if (HornetDetector::capture(20)) {
            probaHornet = HornetDetector::getHornetScore();
          }
        }
        lastHornet_sound = (uint8_t)(probaHornet * 100);

        if (probaHornet > 0.70) {
          DEBUG_PRINTLN("Camera");
          etatActuel = ETAT_ANALYSE_CAMERA;
        } else {
          //DEBUG_PRINTLN("=> Rien de suspect. Retour vérification.");
          etatActuel = ETAT_SOMMEIL;
        }
      }
      break;

    /* Payload 4 octets : req_id score_1 score_1 score_1 */
    case ETAT_ANALYSE_CAMERA:
      {

        comptForceCam = 0;

        digitalWrite(PIN_WAKE_OUT, HIGH);
        delay(500);

        uint8_t type, len;
        uint8_t payload[32];
        bool got_result = false;
        uint32_t t0 = millis();

        uint8_t frame_id = 0;

        // On attend une trame valide envoyée automatiquement par la XIAO
        while ((millis() - t0) < 5000) {
          if (recv_packet(type, payload, len, 800000)) {

            if (type == RESULT && len == 4) {
              frame_id = payload[0];
              lastHornet = payload[1];
              lastBee = payload[2];
              lastBees = payload[3];

              // lastStatus n'est plus transmis par la XIAO
              // On le reconstruit localement si besoin
              lastStatus = (lastHornet > 0) ? 1 : 0;

              DEBUG_PRINT("Frame ID : ");
              DEBUG_PRINTLN(frame_id);

              DEBUG_PRINT("Hornet % = ");
              DEBUG_PRINTLN(lastHornet);

              DEBUG_PRINT("Bee % = ");
              DEBUG_PRINTLN(lastBee);

              DEBUG_PRINT("Bees % = ");
              DEBUG_PRINTLN(lastBees);

              got_result = true;
              break;
            } else if (type == ERROR_MSG && len >= 2) {
              DEBUG_PRINT("Camera error, frame=");
              DEBUG_PRINT(payload[0]);
              DEBUG_PRINT(" code=");
              DEBUG_PRINTLN(payload[1]);
              got_result = false;
              break;
            }
          }
        }

        digitalWrite(PIN_WAKE_OUT, LOW);

        if (!got_result) {
          etatActuel = ETAT_SOMMEIL;
        } else {
          request_id++;

          if (lastHornet > 0) {
            etatActuel = ETAT_ENVOI_LORAWAN;
          } else {
            etatActuel = ETAT_SOMMEIL;
          }
        }
      }
      break;

    case ETAT_ENVOI_LORAWAN:
      digitalWrite(PIN_SHDN, HIGH);
      delay(100);

      if (connectToTTN()) {
        String loraPayload = buildLoRaPayload();
        sendLoRaPayload(loraPayload);
        cyclesSansEnvoi = 0;

        DEBUG_PRINTLN("Attente Downlink (RX1/RX2)...");
        unsigned long listenStart = millis();
        // On écoute pendant 5 à 10 secondes pour être sûr de capter le message RX
        while (millis() - listenStart < 8000) {
          checkDownlink();
          delay(10);  // Petit délai pour laisser le buffer série se remplir
        }

      } else {
        DEBUG_PRINTLN("Échec du JOIN avant envoi");
      }

      lastHornet_sound = 0;  // Sera utilisé pour t_5
      lastQueen_sound = 0;   // Sera utilisé pour t_4
      lastHornet = 0;        // Sera utilisé pour t_1
      lastBee = 0;           // Sera utilisé pour t_2
      lastBees = 0;          // Sera utilisé pour t_3
      lastStatus = 0;        // Sera utilisé pour t_0 (0-3)

      digitalWrite(PIN_SHDN, LOW);
      etatActuel = ETAT_SOMMEIL;
      break;
  }
}

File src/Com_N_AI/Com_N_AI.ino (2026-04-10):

#include <Arduino.h>
#include <BeeGuardAI_Hornet_Bee_Bees_G1V2_inferencing.h>
#include "esp_camera.h"
#include <ctype.h>
#include <string.h>

// Décommente cette ligne pour activer le debug série
//#define DEBUG_XIAO

// =====================================================
// XIAO ESP32S3 Sense - émission continue tant que l'alim existe
// - auto démarrage au boot
// - capture caméra + inference Edge Impulse
// - envoi continu des scores de confiance (%)
// - aucune réception UART
// - aucune commande RUN/SLEEP
// - checksum XOR à la fin de chaque trame
// - arrêt uniquement par coupure d'alimentation externe
// =====================================================

// =====================================================
// Configuration Pins
// =====================================================
static const int PIN_TX = D6;
static const uint32_t BAUD = 4800;
static const uint32_t BIT_US = 1000000UL / BAUD;

// Intervalle entre 2 trames
static const uint32_t LOOP_DELAY_MS = 200;

// =====================================================
// Protocole
// Trame :
// [0]  0xA5
// [1]  0x5A
// [2]  type
// [3]  len
// [4..] payload
// [fin] checksum XOR de tous les octets précédents
// =====================================================
enum MsgType : uint8_t {
  RESULT    = 0x02,
  ERROR_MSG = 0x05
};

enum ErrorCode : uint8_t {
  ERR_NONE            = 0x00,
  ERR_CAMERA_CAPTURE  = 0x01,
  ERR_CLASSIFIER      = 0x02
};

// =====================================================
// Configuration Caméra OV2640
// =====================================================
#define PWDN_GPIO_NUM    -1
#define RESET_GPIO_NUM   -1
#define XCLK_GPIO_NUM    10
#define SIOD_GPIO_NUM    40
#define SIOC_GPIO_NUM    39
#define Y9_GPIO_NUM      48
#define Y8_GPIO_NUM      11
#define Y7_GPIO_NUM      12
#define Y6_GPIO_NUM      14
#define Y5_GPIO_NUM      16
#define Y4_GPIO_NUM      18
#define Y3_GPIO_NUM      17
#define Y2_GPIO_NUM      15
#define VSYNC_GPIO_NUM   38
#define HREF_GPIO_NUM    47
#define PCLK_GPIO_NUM    13

static constexpr int IN_W = EI_CLASSIFIER_INPUT_WIDTH;
static constexpr int IN_H = EI_CLASSIFIER_INPUT_HEIGHT;
static constexpr size_t IN_CH = 3;
static constexpr size_t SNAPSHOT_BYTES = (size_t)IN_W * (size_t)IN_H * IN_CH;

static camera_config_t camera_config = {
  .pin_pwdn       = PWDN_GPIO_NUM,
  .pin_reset      = RESET_GPIO_NUM,
  .pin_xclk       = XCLK_GPIO_NUM,
  .pin_sscb_sda   = SIOD_GPIO_NUM,
  .pin_sscb_scl   = SIOC_GPIO_NUM,
  .pin_d7         = Y9_GPIO_NUM,
  .pin_d6         = Y8_GPIO_NUM,
  .pin_d5         = Y7_GPIO_NUM,
  .pin_d4         = Y6_GPIO_NUM,
  .pin_d3         = Y5_GPIO_NUM,
  .pin_d2         = Y4_GPIO_NUM,
  .pin_d1         = Y3_GPIO_NUM,
  .pin_d0         = Y2_GPIO_NUM,
  .pin_vsync      = VSYNC_GPIO_NUM,
  .pin_href       = HREF_GPIO_NUM,
  .pin_pclk       = PCLK_GPIO_NUM,
  .xclk_freq_hz   = 20000000,
  .ledc_timer     = LEDC_TIMER_0,
  .ledc_channel   = LEDC_CHANNEL_0,
  .pixel_format   = PIXFORMAT_RGB565,
  .frame_size     = FRAMESIZE_QVGA,
  .jpeg_quality   = 12,
  .fb_count       = 1,
  .fb_location    = CAMERA_FB_IN_PSRAM,
  .grab_mode      = CAMERA_GRAB_WHEN_EMPTY,
};

static uint8_t *snapshot = nullptr;
static uint8_t g_frame_id = 0;

// =====================================================
// Structures
// =====================================================
struct Scores {
  uint8_t hornet; // 0..100
  uint8_t bee;    // 0..100
  uint8_t bees;   // 0..100
};

// =====================================================
// Prototypes
// =====================================================
static inline void bb_wait_bit();
void bb_tx_byte(uint8_t b);
void send_packet(uint8_t type, const uint8_t *payload, uint8_t len);

bool capture_to_snapshot_rgb();
int ei_get_data(size_t offset, size_t length, float *out_ptr);

static bool str_ieq(const char *a, const char *b);
static uint8_t score_to_percent(float v);

bool run_inference_and_score(Scores &scores, ei_impulse_result_t &result);
void send_result_frame(uint8_t frame_id);
void send_error_frame(uint8_t frame_id, uint8_t err);
void debugInferenceAndPayload(const Scores &scores, const ei_impulse_result_t &result, const uint8_t *payload, uint8_t len);

// =====================================================
// Bit-bang UART TX only
// =====================================================
static inline void bb_wait_bit() {
  delayMicroseconds(BIT_US);
}

void bb_tx_byte(uint8_t b) {
  noInterrupts();

  digitalWrite(PIN_TX, LOW);
  bb_wait_bit();

  for (int i = 0; i < 8; i++) {
    digitalWrite(PIN_TX, (b & 0x01) ? HIGH : LOW);
    bb_wait_bit();
    b >>= 1;
  }

  digitalWrite(PIN_TX, HIGH);
  bb_wait_bit();

  interrupts();
}

void send_packet(uint8_t type, const uint8_t *payload, uint8_t len) {
  uint8_t chk = 0;

  bb_tx_byte(0xA5); chk ^= 0xA5; delay(2);
  bb_tx_byte(0x5A); chk ^= 0x5A; delay(2);
  bb_tx_byte(type); chk ^= type; delay(2);
  bb_tx_byte(len);  chk ^= len;  delay(2);

  for (uint8_t i = 0; i < len; i++) {
    bb_tx_byte(payload[i]);
    chk ^= payload[i];
    delay(2);
  }

  // checksum XOR final
  bb_tx_byte(chk);
  delay(2);
}

// =====================================================
// Capture image
// =====================================================
bool capture_to_snapshot_rgb() {
  for (int i = 0; i < 3; i++) {
    camera_fb_t *tmp = esp_camera_fb_get();
    if (tmp) esp_camera_fb_return(tmp);
  }

  camera_fb_t *fb = esp_camera_fb_get();
  if (!fb) return false;

  if (fb->format != PIXFORMAT_RGB565) {
    esp_camera_fb_return(fb);
    return false;
  }

  if (!snapshot) {
    snapshot = (uint8_t *)malloc(SNAPSHOT_BYTES);
    if (!snapshot) {
      esp_camera_fb_return(fb);
      return false;
    }
  }

  const float scale_x = (float)fb->width / (float)IN_W;
  const float scale_y = (float)fb->height / (float)IN_H;

  uint8_t *dst = snapshot;

  for (int y = 0; y < IN_H; y++) {
    int src_y = (int)(y * scale_y);
    if (src_y >= (int)fb->height) src_y = fb->height - 1;

    for (int x = 0; x < IN_W; x++) {
      int src_x = (int)(x * scale_x);
      if (src_x >= (int)fb->width) src_x = fb->width - 1;

      size_t px_off = ((size_t)src_y * (size_t)fb->width + (size_t)src_x) * 2;
      if (px_off + 1 >= fb->len) {
        esp_camera_fb_return(fb);
        return false;
      }

      uint16_t p = (uint16_t)fb->buf[px_off] | ((uint16_t)fb->buf[px_off + 1] << 8);

      *dst++ = (uint8_t)(((p >> 11) & 0x1F) * 255 / 31);
      *dst++ = (uint8_t)(((p >> 5)  & 0x3F) * 255 / 63);
      *dst++ = (uint8_t)(((p >> 0)  & 0x1F) * 255 / 31);
    }
  }

  esp_camera_fb_return(fb);
  return true;
}

int ei_get_data(size_t offset, size_t length, float *out_ptr) {
  for (size_t i = 0; i < length; i++) {
    out_ptr[i] = (float)snapshot[offset + i] - 128.0f;
  }
  return 0;
}
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

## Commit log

2026-03-02 Template fonctionnel pour les capteurs
    Template pour utilisation des capteurs sur arduino MKR WAN 1310. Ce template est à adapter pour arduino nano BLE
    Sont intégré: luxmètre, DHT11, Buzzer.
    Les métriques remontées : température, humidité, luminosité, indicateur Sonor de la mise en fonctionnement de l'équipement.
    [testDHT22_serial.ino]
2026-03-03 ajout d'une fonctionnalité de threshold
2026-03-07 Communication unidirectionnelle Bit Banging
    Communication unidirectionnelle Bit Banging XIAO (Master) Arduino NANO BLE (Slave)
2026-03-10 Communication bidirectionnel bit Banging
    Communication bidirectionnel avec payload au bon format :
    [A5] [5A] [TYPE] [LEN] [PAYLOAD...] [CHK]
    A5 5A : préambule
    TYPE : type de message
    LEN : taille payload
    PAYLOAD : données
    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
2026-03-13 Intercommunication avec comptage
    Prototype fonctionnel : intercommunication + comptage simple.
    Code prêt pour l’intégration du deep sleep.
    À faire : adapter les pins selon le pin planner et remplacer le modèle IA par fomo-best-results.
2026-03-16 Connexion à TTN et test des webhook
2026-03-17 architecture complete
    ajout des capteurs
    ajout du lien lora WAN
2026-04-10 version final
    suppression deep sleep, commande de wake up supprimée, from de de la trame modifié

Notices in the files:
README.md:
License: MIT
